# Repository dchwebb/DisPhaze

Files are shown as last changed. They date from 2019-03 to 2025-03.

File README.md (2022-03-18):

# Dis Phaze
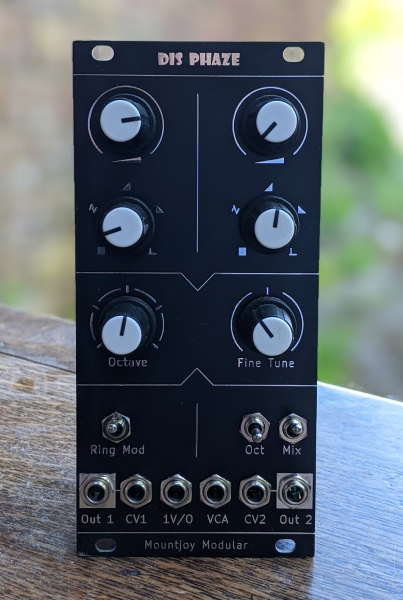
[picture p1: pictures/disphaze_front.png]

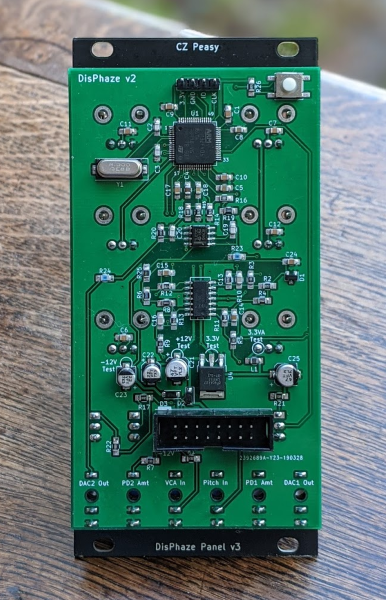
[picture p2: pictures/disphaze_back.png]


Eurorack module providing two Phase Distortion oscillators based on Casio's CZ synthesizors. 

Phase distortion involves warping a sine wave using a second phase distortion signal. The phase distortion tables in this module were loosely based on waveforms sampled from a Casio CZ-1000. Both oscillators allow the sine wave to be warped by a greater amount than on the original and in the case of oscillator 1 the phase distortion tables can be continuously varied.

Functionality
-------------

Disphaze is a two channel design where each channel controls 5 phase distortion waves. These are used to change the playback rate of the audio wave which is always a sine wave. All of the PD waves are based on the CZ but some are generated mathematically, some literally sampled and converted from an original CZ-1000.

The module is duophonic – channel one has a bit more range and so can go more extreme than the CZ. Channel one allows the PD waves morph from one to the next. The second channel does not morph and has a more limited range so it is a bit more 'authentic'. Channel two can also be offset by an octave from channel one which is particularly useful for ring modulation. The module works well in stereo with the two channels split left and right.

Channel one has a Ring Mod switch which digitally multiplies both channel ouputs. Channel two has a mix switch which adds both channel outputs.

The amount of phase distortion applied can be controlled with a knob and/or CV input. Pitch is applied with a 1V/Octave input which is also normalled to the Doepfer standard 16 pin Eurorack connector. The module is also supplied with a VCA input - this allows the use of an envelope generator (or other CV source) to control volume without the need for an external VCA.

Calibration
-----------

 * Set fine tune and both phase distortion amount knobs to the center position
 * Connect a voltage source to the 1V/Oct input
 * Press the calibration button once (top right of back of PCB) - a square wave will be output on channel 1
 * The top left knob will adjust the tuning offset (will be affected by spread setting)
 * The top right knob will adjust the tuning spread (test by checking different octaves)
 * When the calibration is complete press the calibration button again to save

Technical
---------

The heart of the module is the STM32F405 microcontroller running at 168MHz. Timing is generated with an external 8MHz crystal oscillator. CV inputs are conditioned with an MCP6004 OpAmp. The outputs are derived from the Microcontroller's 12 bit DACs amplified via a TL072 OpAmp. The microcontroller is programmed from a 4 pin SWD header.

The module uses a two PCB sandwich construction with vertical potentiometers and jack sockets connecting the two PCBs and providing structural rigidity.
 
 Errata
 ------
 
 * On v2 of the PCB the BOOT0 pin (pin 60) is floating which causes problems programming and debugging over the SWD interface. A bodge wire connects this to ground (pin 2 of C9).
 * Silkscreen for C4 and C17 are incorrectly swapped
 * VDDA is missing decoupling capacitors
 * Reset button missing
 * USB/UART not exposed
 * No silkscreen on calibrate button
 
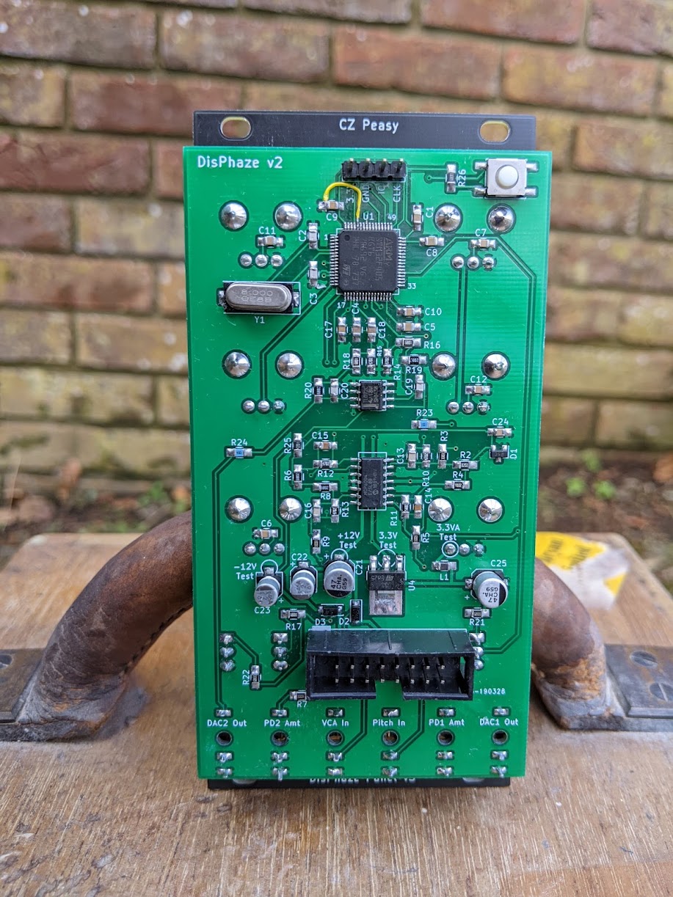
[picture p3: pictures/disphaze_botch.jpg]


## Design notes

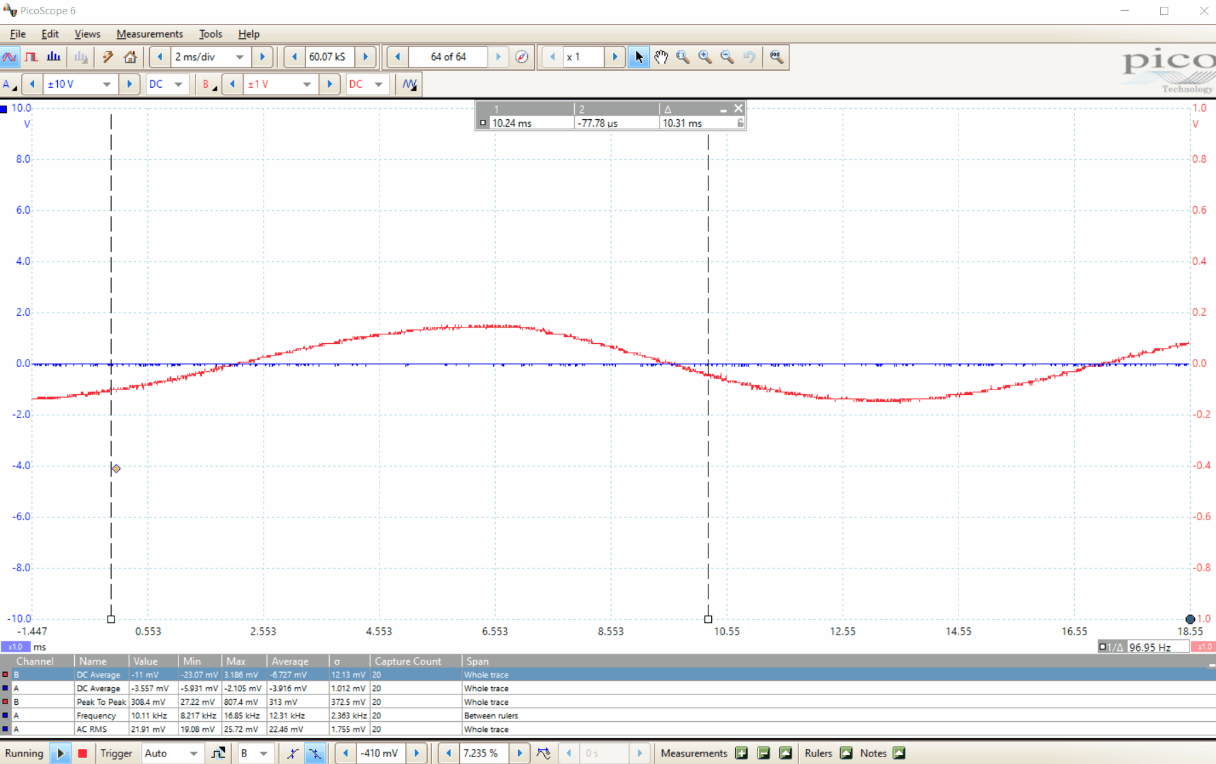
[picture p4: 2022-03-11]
pictures/Casio.gif

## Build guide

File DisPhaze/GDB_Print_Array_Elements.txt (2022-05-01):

In CubeIDE Debugger Console :

#Allow unlimited number of elements to be printed:
set print elements 0

# Prevent <repeats XXX times> messages in print out
set print repeats 0

# Print 10000 elements from array 'buffer' in hex format
print /x *buffer@5000

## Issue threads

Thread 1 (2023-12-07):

What is the Open Source License for this code?

eclab, 2023-12-07:
I'd like to use this code, but it lacks a license.  Can you tell me what license it is distributed under?

eclab, 2023-12-08:
I appreciate this, but without a license, it's a copyright violation use your code: you fully own the copyright.  What a license does is formally declare that we have the right to you use your code and under what conditions.

If you're in the category of "do whatever you want with this", I suggest Apache 2.0, which is a license just like this.  Just slap the Apache 2.0 license text in the top directory of the project, called LICENSE, and call it a day.  Don't even bother modifying the file headers, it's not that important.

dchwebb, 2023-12-08:
Added Apache licence.

eclab, 2023-12-08:
I'm working on a small project for adding PD to Mozzi on the Arduino.  I'm looking for simple PD versions for all the casio waves.  BTW, I think you've been replicating waves from the front panel of the CZ series, but you might be interested that the front panel lies: the way the waves work is entirely different.  In fact, there are eight waveforms, only one of which is "resonance" so to speak (it's often called "multi-sine"), and waves consist of pairs of waveforms plus a window function: there are eight window functions.  So there are technically 8^3 combinations, not 6, though many are duplicates and others are useless.  It'd be really nice to have distortion generators for all eight (well, 7) of the basic waveforms, the rest is easy to put together.  See [the Casio CZ-1 Splunking page](https://www.kasploosh.com/cz/11800-spelunking/4-window/), which is good at explaining it, though it doesn't give any clues as to the specific functions for doing distortion.  [This guy](https://www.kvraudio.com/forum/viewtopic.php?t=201858) got good generators for Saw and Square, and built a resonance function but that's not how resonance works in the CZ: it's just increasingly high-frequency Sine run through a triangle window function.  I've not found any other useful code.

eclab, 2023-12-08:
I am confused a bit by your PD code.  I think you have a fixed PD generator for (say) sawtooth in the form of a lookup table, and what you're doing is cross-fading between it and sine, rather than using parameterizable function generator?  I could be mistaken?  It's not super clear.  This might work in a pinch and I might do that but was hoping to actually find a fast (non-float, non-division, sine only via lookup table) way to produce the distortion functions.

dchwebb, 2023-12-08:
There are a couple of mechanisms going on here. The 'resonance' waves are implemented pretty much how the hardware works.

For the other waves my approach was to 'move' through a sine wave with the speed dictated by the phase distortion look-up table. I then sampled the phase distorted waves from my Casio CZ, built a little program to calculate the look-up table, and stored that.

So I'm not cross-fading between the phase distortion look-up and the sine wave; I'm dynamically adjusting the speed I play back the sine wave based on the scaled phase distortion wave. It's phase distortion, but implemented very differently to the Casio.

I wasn't really aiming for accuracy - more to make a fun homage to the Casio that would work in a Eurorack situation. The sounds tend to be more aggressive than the original and work well in a monophonic situation whereas the original Casio excels as a polyphonic synth (to me, anyway).

eclab, 2023-12-08:
I wonder if that would work in my situation. Lookup tables always good -- I'm on an arduino with no hardware division nor floating point -- but the whole architecture might be too computationally costly... [I'm doing AE Modular GRAINS].

dchwebb, 2023-12-08:
That makes it a lot harder - I am way too lazy to work with fixed point maths. I will generally try and avoid divides anyway, unless they can be implemented as integer bit shifts.

I haven't delved massively deeply into the Casio architecture (the patent document is available but is incredibly complicated). However I am fairly sure they would have used a much simpler method than me for performance on older processors.

I also think that one thing that has a fairly significant impact on the sound is the analog LP filter on the output. I don't know what they are using exactly - it is marked 'LPF17K' on the schematic, so I assume it is filtering at 17 KHz.

eclab, 2023-12-08:
I'm guessing this was an attempt to eliminate aliasing? Or high frequency DAC artifacts?    Probably not filtering prior to downsampling?

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

dchwebb, 2023-12-08:
I'm not exactly sure. The DAC goes to an 'Expander Circuit' and then a 'Sample/Hold Circuit', before being filtered and output. I haven't really looked into what these do but possibly create artifacts that need to be filtered.

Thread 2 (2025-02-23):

New V3 build help

OryH, 2025-02-23:
I ordered the V3 pcb and got it to run on the Disphaze.bin but the two switches on the right (octave and mix) and the led dont seem to work. I then tried uploading the newer DisphazePoly version and just get silence. Im new to the stm32cubeide so if there is anything I should know to get it working I would be greatful.  Thank you for the work you have done on this awesome module I look forward to using it in the years to come. Ory H.   ( I also built the entire module a second time and got the exact same issue)

dchwebb, 2025-02-23:
The v3 hardware should be used with the Poly firmware here: https://github.com/dchwebb/DisPhaze/tree/master/DisPhazePoly/Debug

If you hear nothing when it is connected try connecting an envelope to the VCA input.

The octave switch should be an On-Off-On type and the Mix switch should be an On-On type. Both switches just affect the output of the second channel 'Out 2', so will not have an effect on the 'Out 1' output.

The LED is a dual LED arranged as Anode-Cathode-Anode (some are the other way round).

Finally can you confirm that the crystal is 12MHz?

Let me know if any of that helps.

dchwebb, 2025-02-24:
Also a bit more explanation on the v3 hardware/poly firmware. This was designed as an experiment to create a polyphonic version of the module. You can switch between monophonic/polyphonic modes by long-pressing the button on the front. In monophonic mode connect a 1/v oct pitch signal and (optionally) an envelope to the VCA to control level.

In polyphonic mode you need to first set up an envelope for the notes. Attach an ADSR envelope to the ENV input and then press the button. You then trigger an envelope which will be sampled into the module. Once the envelope is sampled the module will play back the polyphonic notes using envelopes based on the ones sampled.

In polyphonic mode note input is via MIDI - either the USB connection or using a 3.5mm MIDI signal to the 1V/O input (note you need a stereo input jack for this to work.

I did have some problems with the action button on my original prototype. This is originally connected to pin PB5 but I bodged in a connection to PB10 which the firmware is currently configured for. I'll try and do some more testing to see if I can get it working with PB5 to avoid you having to carry out this fiddly bodge yourself.

OryH, 2025-02-26:
Thank you for the help. I built a third module with a new batch of stm32f405rgt6 from aliexpress and it didn't work at all so then i swapped it with a known working one from digikey and it worked but again only running the original disphaze.bin file. So maybe that could be a clue as I could have a different version of stm32 then the one you were running. I also replaced the 12mhz crystal and the 30pf caps and swapped all the 100nf decoupling capacitors around the microcontroller and still the same. Ill keep trying and If I figure it out ill post here. Either way it sounds really good even in its monophonic mode.

OryH, 2025-03-01:
Yes I will totally send it over to you if that helps you design these awesome modules. With the older firmware I can get audio output from both channels, the VCA and CV's respond to cv, the envelope works as does the pitch input. However when I use the poly version firmware there is no sound output with midi over usb connected to a Monome Norns or using a 3.5mm jack connected to a Westlicht Performers midi out etc..  It could be an issue with my midi gear some my soldering or some other problem. Let me know where to send the module and I greatly appreciate your help.

Ory H.

dchwebb, 2025-03-01:
If you send a message to dchwebb@gmail.com I'll give you my address.

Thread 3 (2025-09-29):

audio output level to low with my old version Hardware 3.0

tsanderakis, 2025-09-29:
Was working the last two weeks on a DisPhaze 3.0. The PCBs came some month ago.
Everything seems to work fine, all pots and switches, VCA LED going on/off when a gate is connectet but audio output level is to low when standing side by side to kishoof. Something wrong from my side or is there any chance to push the level a little bit more up?
And, because could not find a photo, had some trouble with the orientation of ÚSB port.  Could not not find the 1 and I`m not shure if it is the right way around. The firmware went by Disco Board onto the module.

dchwebb, 2025-09-29:
Just to confirm - is this the 3.0 rather than the 3.5 version? In any case the gain of the output is set by the resistors R17/R18 and R21/R22. So if you built the v3.0 version you have 68k/6.8k = 10x gain.

The output level could also be affected by R19 and R23. These are output protection resistors and are probably too high. You could try changing them for 100 ohm resistors and seeing if that helps.

I don't have the module in front of me but will find it and check orientation of USB.

tsanderakis, 2025-09-29:
ok, thank you. Will check this later.
In the moment I have a new module from Maffez from Austria on the table and try to get it ready to give him some response.
Could not get it ready last week because out of 3,5 mm jacks. But they are in the mail for today.
It`s the older 3.0 version. In the moment USB is not connecting to computer. Ok, could also be some cold joints.

tsanderakis, 2025-09-29:
Then I hope that I don`t have tu turn around the USB socket. In the moment the connection is not working and a few days ago I turned it around because it was also not working. But what is now the right direktin? When looking to the front the small part is pointing down to bottom. Could not find the 1 marking on the socket. PCB is fine.

dchwebb, 2025-09-29:
I can't find the module at present (we have just moved house) but it should look like this (I think):

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

tsanderakis, 2025-09-29:
Then I`m the wrong way around. Then it needs a little bit surgery on the kitchentable and I hope that I will not destroy something.
Good that I have not soldered the ground, just the small 4 connectors.
Thank you for looking. Let you know late if everything went good.

tsanderakis, 2025-09-29:
help
Mountjoy DisPhaze Poly - supported commands:

help           -  Shows this information
info           -  Display current settings
dfu            -  USB firmware upgrade
poly           -  Switches between polyphonic and monophonic mode
attack:x.xx    -  Set polyphonic attack time in ms
decay:x.xx     -  Set decay time in ms
sustain:x.xx   -  Set sustain 0.0 - 1.0
release:x.xx   -  Set envelope release time in ms
comphold:x.xx  -  Set compressor hold time in ms
comprel:x.xx   -  Set compressor release rate
compthresh:x.xx-  Set compressor threshold
info
Build Date: Mar 23 2025 12:01:45
Polyphonic mode: off
VCA Envelope: A: 1.00 ms, D: 50.00 ms, S: 0.50, R: 50.00 ms
Compressor: Hold time 350.00 ms; Release: 0.00000010; Threshold: 0.50
Calibration base: 2220.42, mult: 587.00
Config sector: 8; address: 0x8080000

looks good but where are my octaves?

dchwebb, 2025-09-29:
Fair point. You have to type 'calib'.

tsanderakis, 2025-09-29:
Some strange things were going on. Kicked the Seabooard out of the chain and replaced it with my old Midiplus 61.
When calibrating I used my Ornament & Crime and this was calibrated with a multimeter with 60.000 reading, so for me ok.
When changing the octaves from O&C, 0V, 1V, 2V, 3V.... everything was fine.  Going to MidiMonger octaves were not ok with Seaboard and PSU.
Replaced then Seaboard by Midiplus 61 to have something simple and now the STM on DisPhaze was running hot switching my test PSU on and off like hell and the STM is hot that you can burn your finger.
For the moment I try to cool it down and check later after some food and a beer if it is still alive. If not, things are goin complicated.
First I was thinking to cool the STM down with spray but I have the time to do it in natural way.

tsanderakis, 2025-10-04:
Could not find out whats wrong with No. 1. Checked all connections with big magnifying glasses  and lots of light.
Last chance is maybe changing the STM.
Started with a second one, No.2.
Don`t wanted to have a surprise and checked it before mounting potentiometers and other stuff. Same problem?
Later I will do No3. from the same batch of processors and just soldering the processor and nothing else. If I have the same problem then there must bei somemething wrong with PCBs or are the processors fake??

dchwebb, 2025-10-05:
Apologies I am away in Japan so can't access my computer. However I think
there was a problem with one of the buttons on the module shorting to
ground. I did a fairly fiddly hardware botch to resolve and then released
v3.5 to fix. Unfortunately it looks like your pcbs are the old version.
When I am back I will have a more detailed look at the hardware botch I
made. In the meantime I don't recommend trying to build any more as I don't
think it will help.
Sorry not to be more helpful at this stage!

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

tsanderakis, 2025-10-05:
Thank you.
Have a nice trip.

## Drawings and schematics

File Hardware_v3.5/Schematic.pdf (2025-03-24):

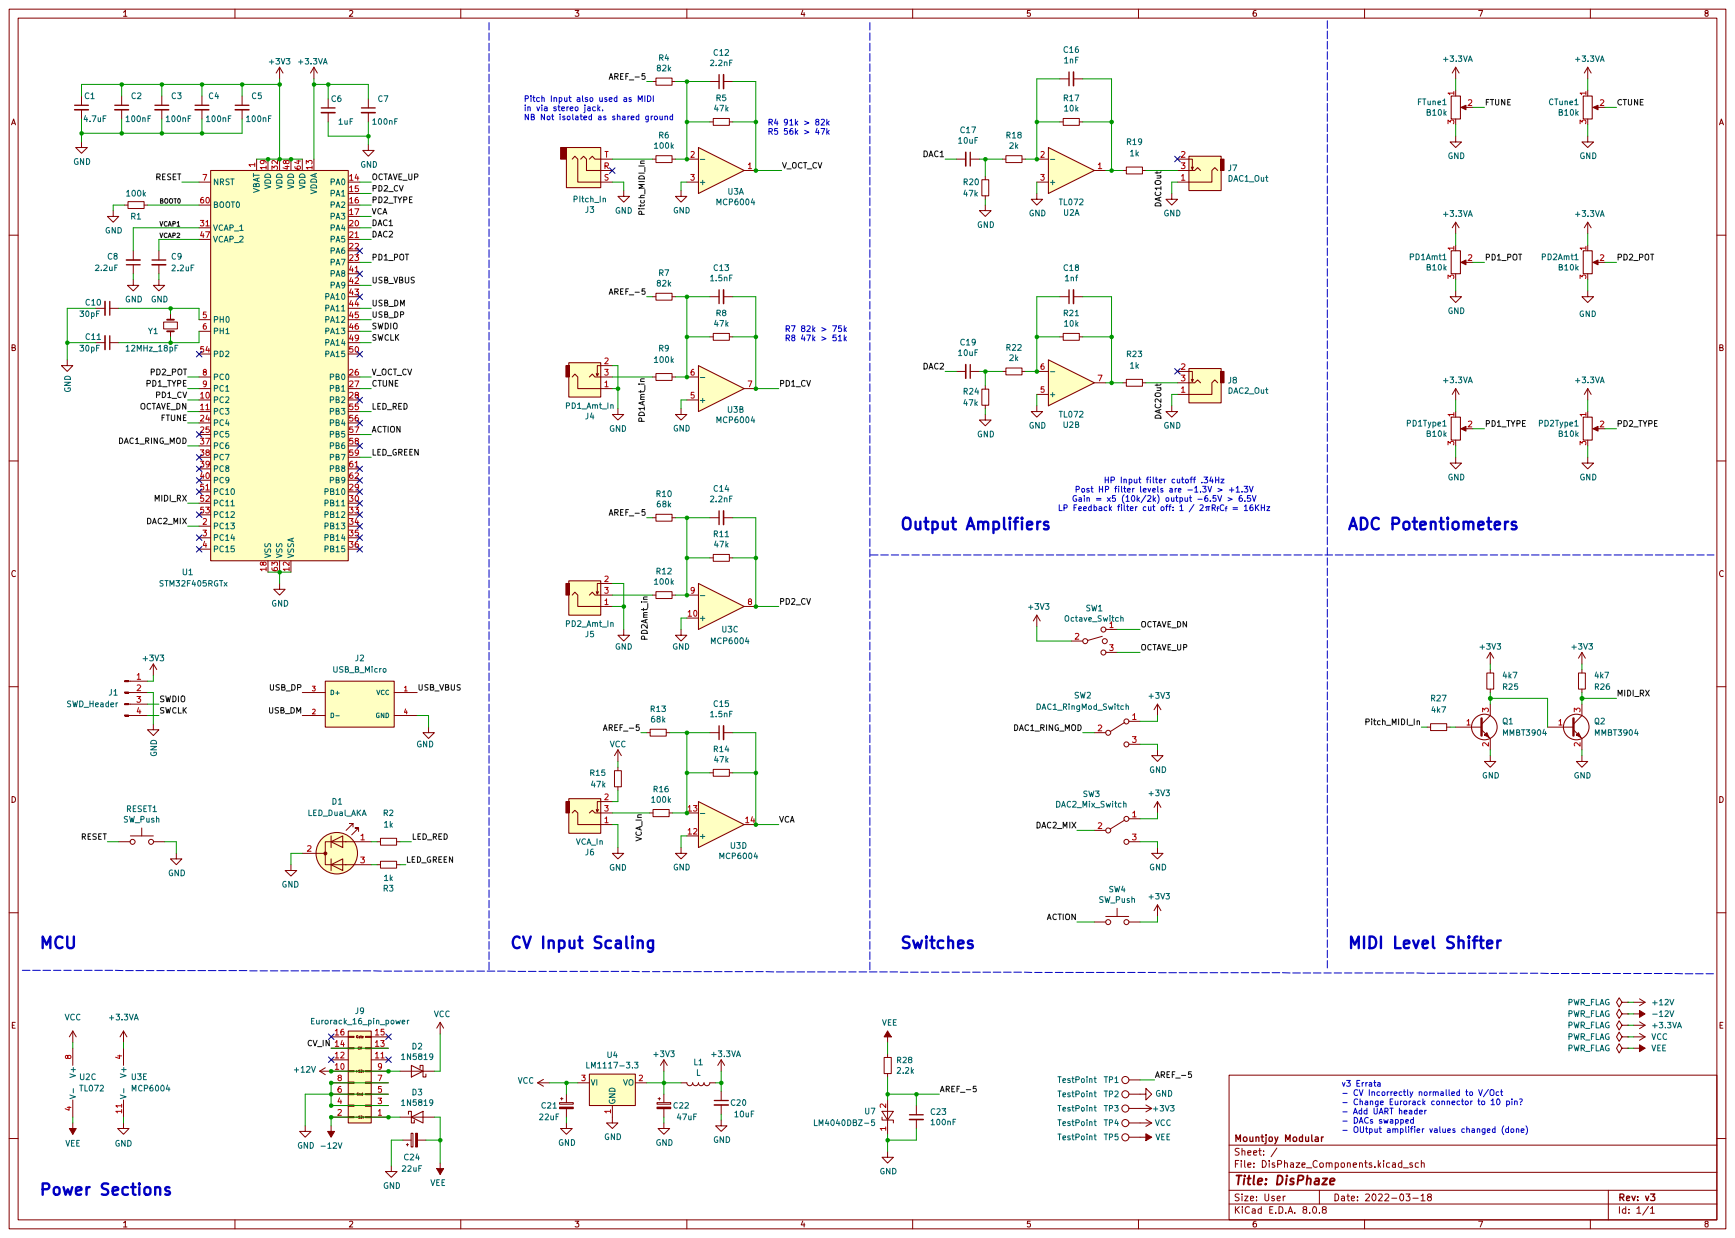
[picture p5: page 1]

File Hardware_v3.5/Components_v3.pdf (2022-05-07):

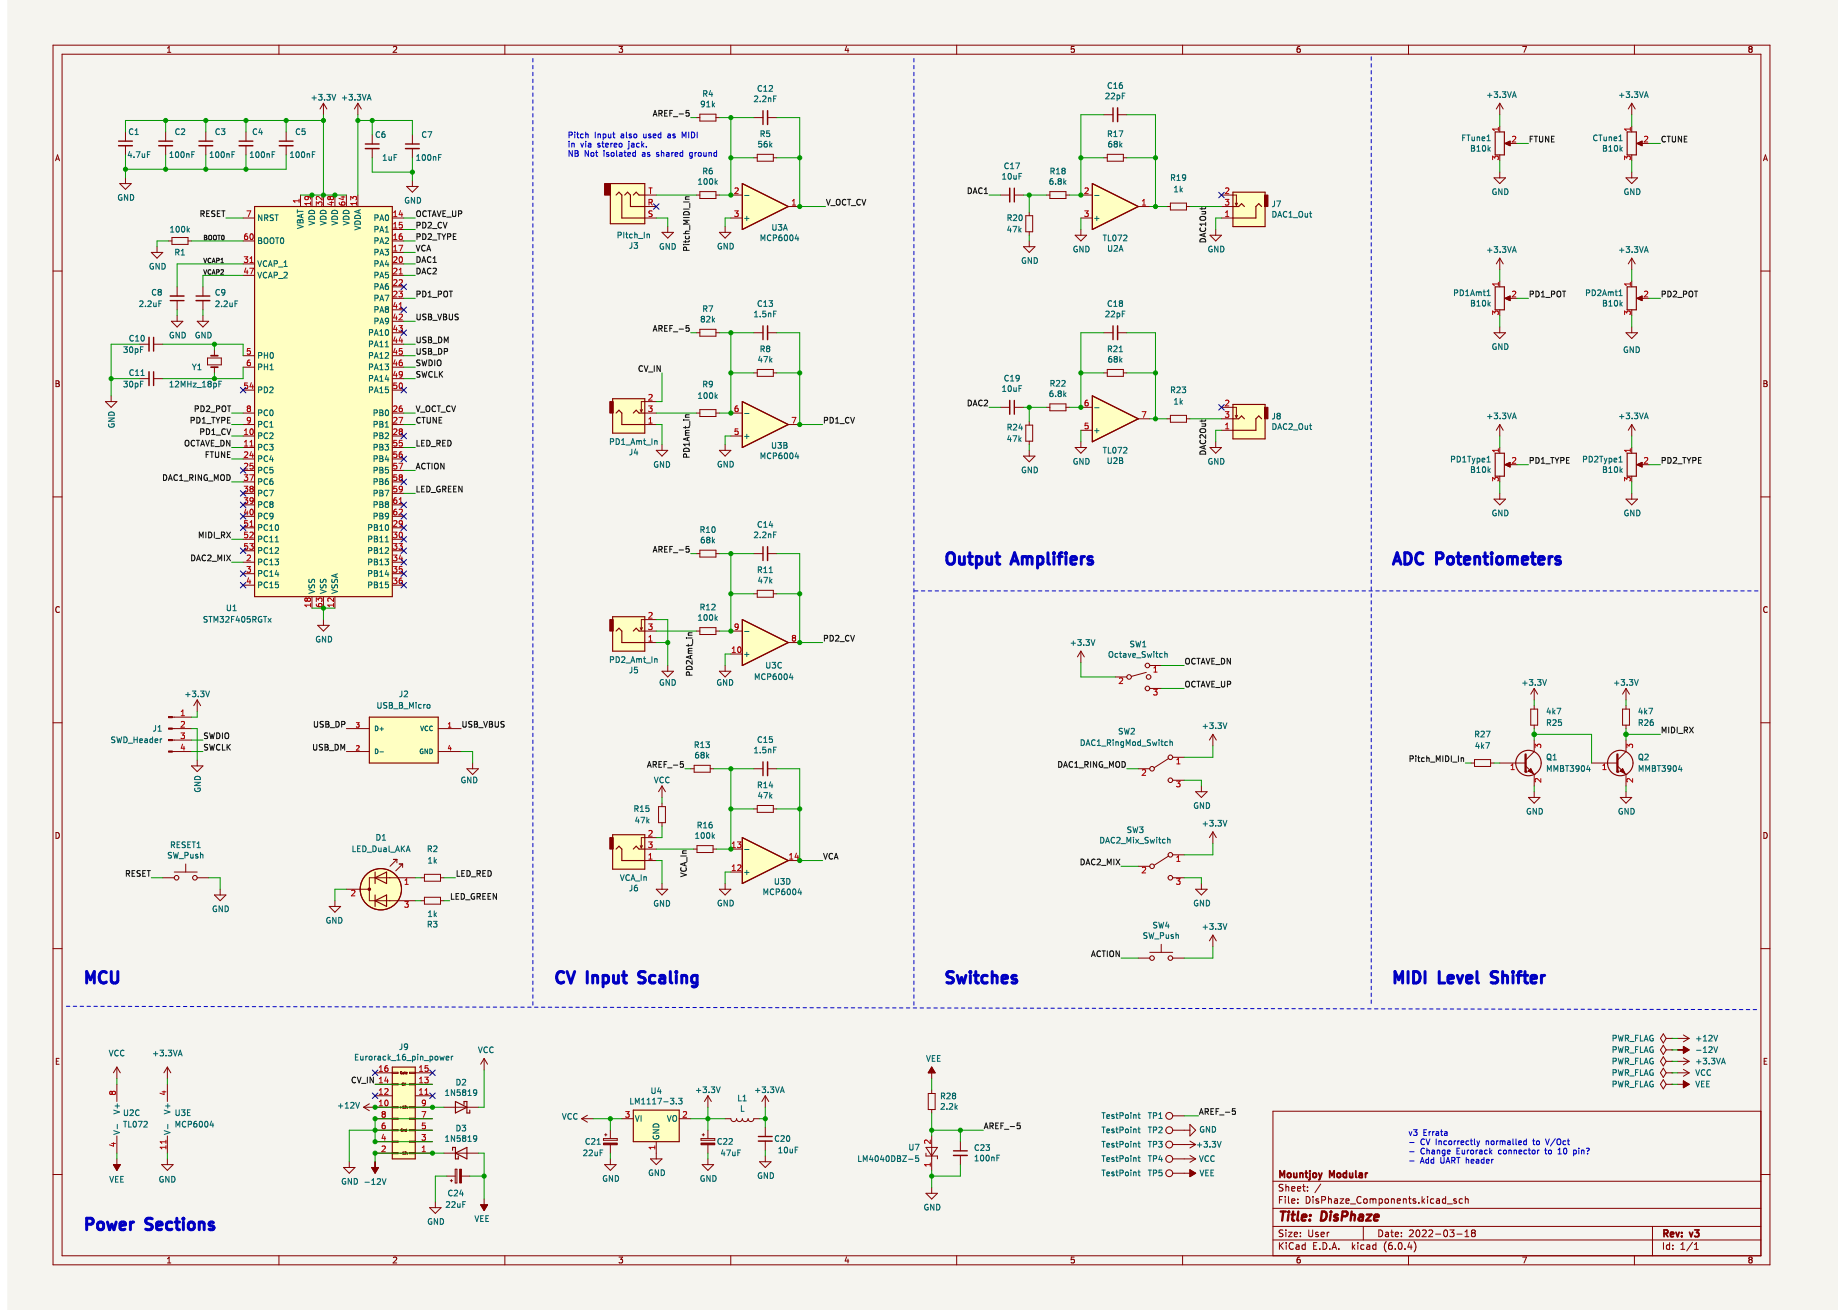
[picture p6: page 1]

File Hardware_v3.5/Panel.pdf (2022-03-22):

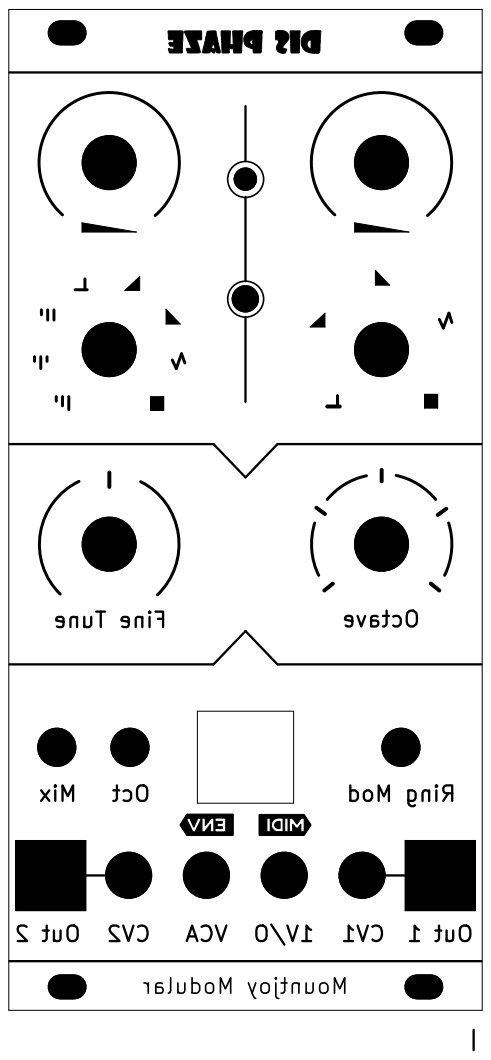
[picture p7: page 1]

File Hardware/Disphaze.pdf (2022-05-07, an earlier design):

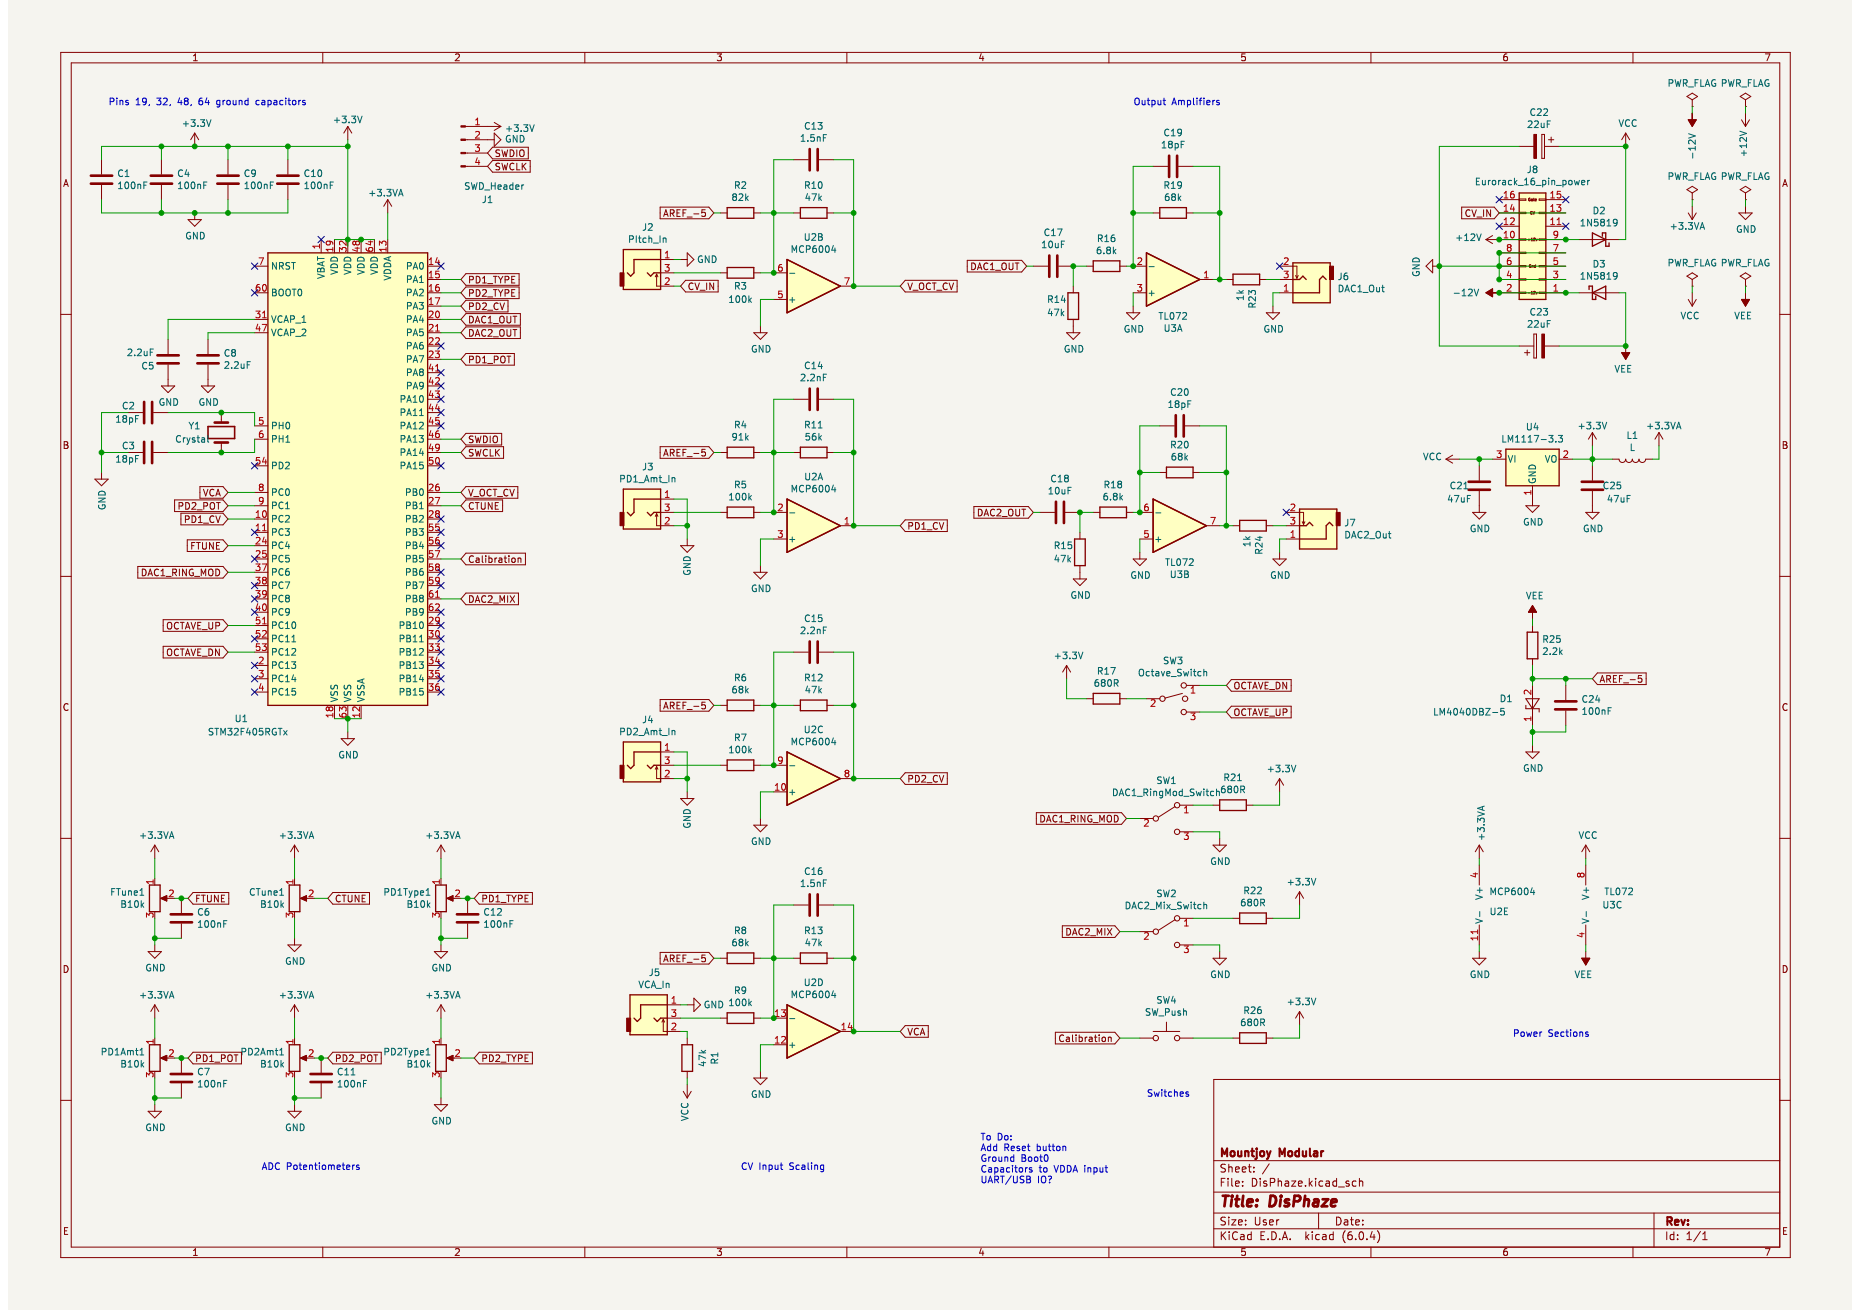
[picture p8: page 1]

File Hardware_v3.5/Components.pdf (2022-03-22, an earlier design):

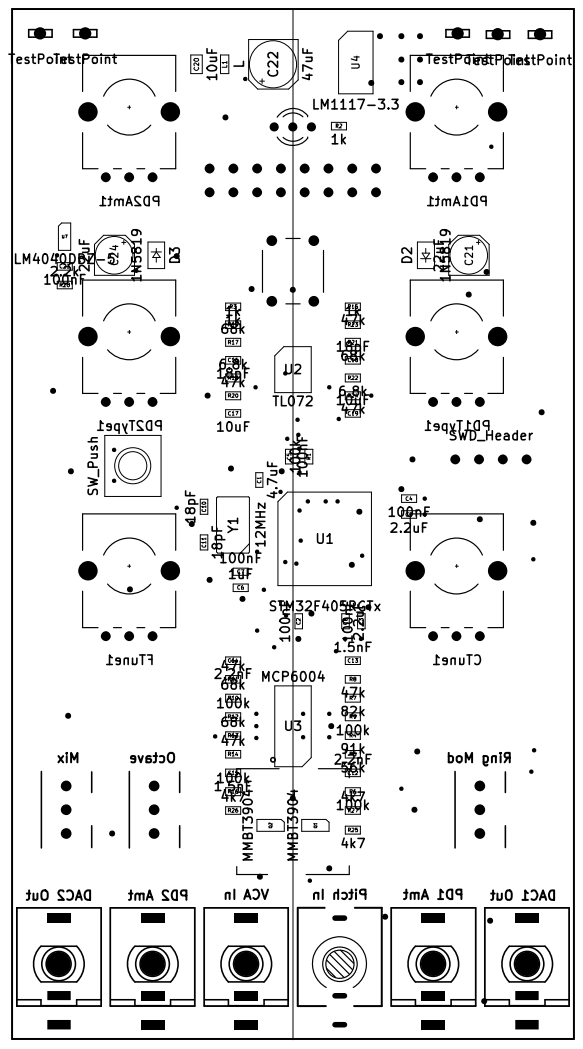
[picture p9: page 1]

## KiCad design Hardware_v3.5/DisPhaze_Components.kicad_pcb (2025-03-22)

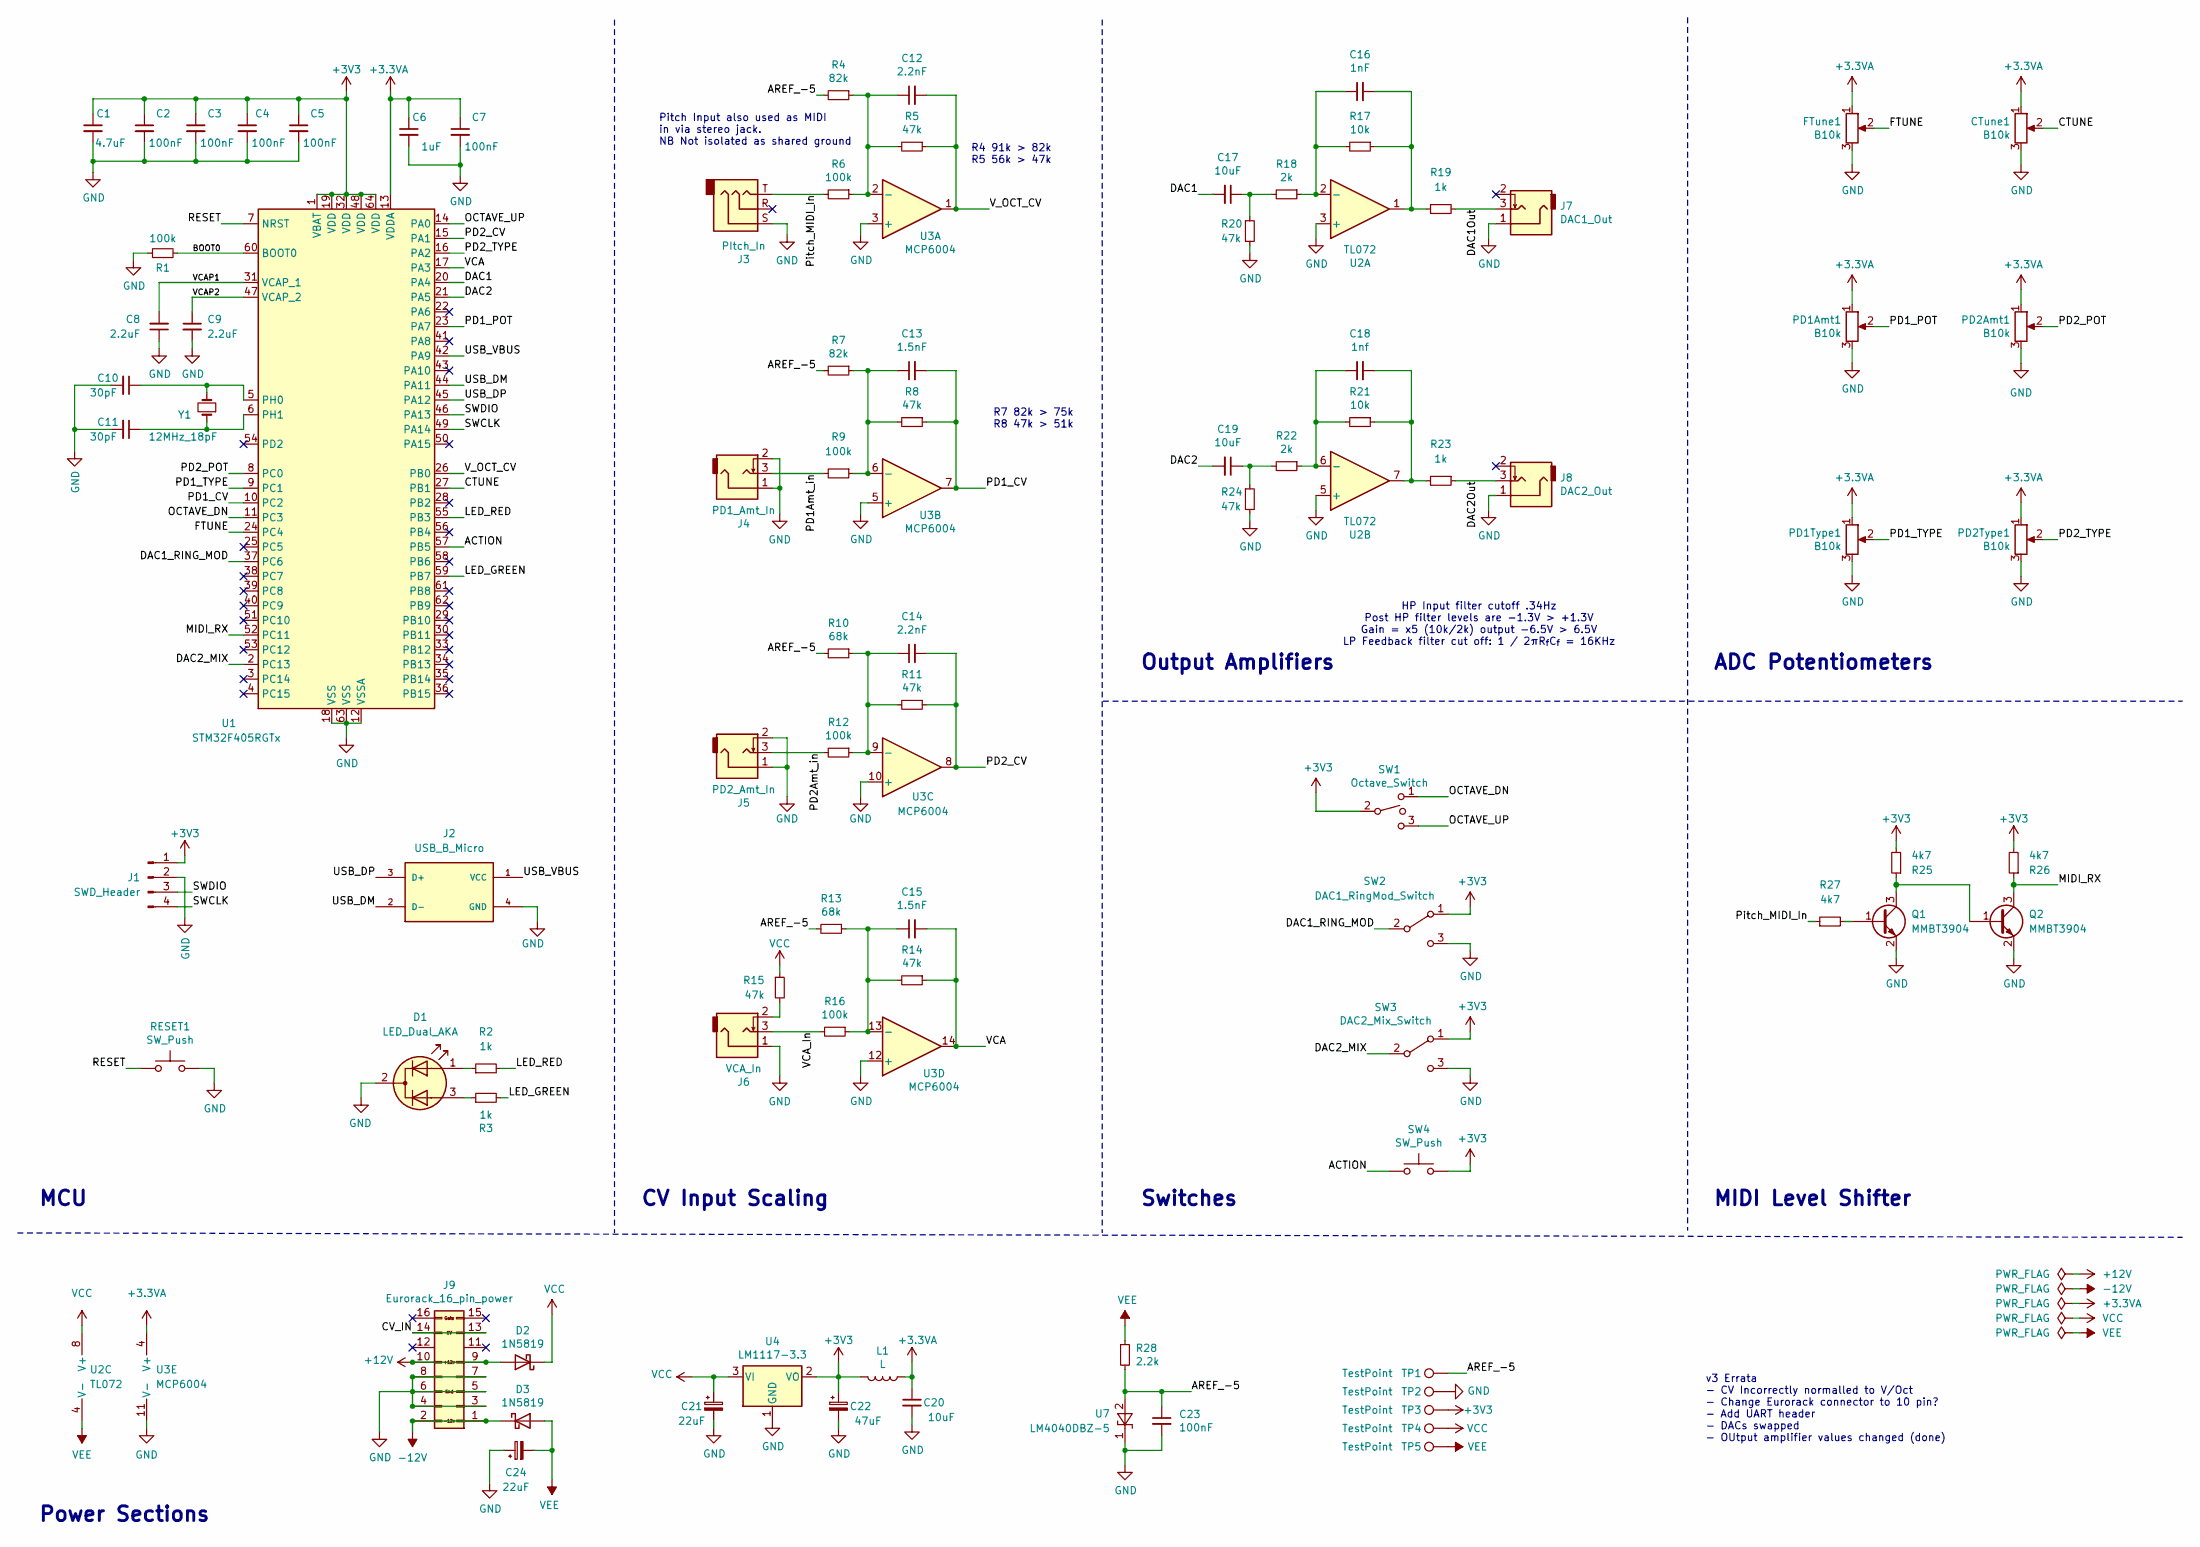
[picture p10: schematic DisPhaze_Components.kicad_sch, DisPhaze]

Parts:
C1: 4.7uF; C_0603_1608Metric
C2, C3, C4, C5, C7, C23: 100nF; C_0603_1608Metric
C6: 1uF; C_0603_1608Metric
C8, C9: 2.2uF; C_0603_1608Metric
C10, C11: 30pF; C_0603_1608Metric
C12, C14: 2.2nF; C_0603_1608Metric
C13, C15: 1.5nF; C_0603_1608Metric
C16: 1nF; C_0603_1608Metric
C17, C19: 10uF; C_0603_1608Metric
C18: 1nf; C_0603_1608Metric
C20: 10uF; C_0805_2012Metric
C21, C24: 22uF; CP_Elec_4x5.3
C22: 47uF; CP_Elec_5x5.4
CTune1: B10k; Alpha_9mm_Potentiometer_Aligned
D1: LED_Dual_AKA; LED_D3.0mm-3
D2, D3: 1N5819; D_SOD-123
FTune1: B10k; Alpha_9mm_Potentiometer_Aligned
J1: SWD_Header; SWD_header
J2: USB_B_Micro; USB_TE_1734517-1
J3: PItch_In; Thonkiconn_Stereo-PJ366ST
J4: PD1_Amt_In; THONKICONN_hole
J5: PD2_Amt_In; THONKICONN_hole
J6: VCA_In; THONKICONN_hole
J7: DAC1_Out; THONKICONN_hole
J8: DAC2_Out; THONKICONN_hole
J9: Eurorack_16_pin_power; Eurorack_16_pin_header
L1: L; L_0805_2012Metric
PD1Amt1, PD1Type1, PD2Amt1, PD2Type1: B10k; Alpha_9mm_Potentiometer_Aligned
Q1, Q2: MMBT3904; SOT-23; Part_Number C20526
R1: 100k; R_0603_1608Metric; Part_Number C25803
R2, R3, R19, R23: 1k; R_0603_1608Metric
R4, R7: 82k; R_0603_1608Metric
R5, R8, R11, R14, R15, R20, R24: 47k; R_0603_1608Metric
R6, R9, R12, R16: 100k; R_0603_1608Metric
R10, R13: 68k; R_0603_1608Metric
R17, R21: 10k; R_0603_1608Metric
R18, R22: 2k; R_0603_1608Metric
R25, R26, R27: 4k7; R_0603_1608Metric; Part_Number C23162
R28: 2.2k; R_0603_1608Metric
RESET1: SW_Push; SW_SPST_EVQQ2
SW1: Octave_Switch; SPDTSubMiniature
SW2: DAC1_RingMod_Switch; SPDTSubMiniature
SW3: DAC2_Mix_Switch; SPDTSubMiniature
SW4: SW_Push; SW_PUSH_6mm_aligned
TP1, TP2, TP3, TP4, TP5: TestPoint; 1.3mm_Test_Point
U1: STM32F405RGTx; LQFP-64_10x10mm_P0.5mm
U2: TL072; SOIC-8_3.9x4.9mm_P1.27mm
U3: MCP6004; SOIC-14_3.9x8.7mm_P1.27mm
U4: LM1117-3.3; SOT-223-3_TabPin2
U7: LM4040DBZ-5; SOT-23
Y1: 12MHz_18pF; Crystal_SMD_0603-2Pin_6.0x3.5mm

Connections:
+3.3VA: C6.1, C7.1, C20.1, CTune1.1, FTune1.1, L1.1, PD1Amt1.1, PD1Type1.1, PD2Amt1.1, PD2Type1.1, U1.13 (VDDA), U3.4 (V+)
+3V3: C1.1, C2.1, C3.1, C4.1, C5.1, C22.1, J1.1, L1.2, R25.2, R26.2, SW1.2, SW2.1 (A), SW3.1 (A), SW4.2, TP3.1, U1.1 (VBAT), U1.19 (VDD), U1.32 (VDD), U1.48 (VDD), U1.64 (VDD), U4.2 (VO)
+12V: D2.2 (A), J9.9, J9.10
-12V: D3.1 (K), J9.1, J9.2
/ACTION: SW4.1, U1.57 (PB5)
/AREF_-5: C23.1, R4.2, R7.2, R10.2, R13.2, R28.2, TP1.1, U7.2 (A)
/BOOT0: R1.2, U1.60 (BOOT0)
/CTUNE: CTune1.2, U1.27 (PB1)
/CV_IN: J9.13, J9.14
/DAC1: C17.2, U1.20 (PA4)
/DAC1Out: J7.3, R19.2
/DAC1_RING_MOD: SW2.2 (B), U1.37 (PC6)
/DAC2: C19.2, U1.21 (PA5)
/DAC2Out: J8.3, R23.1
/DAC2_MIX: SW3.2 (B), U1.2 (PC13)
/FTUNE: FTune1.2, U1.24 (PC4)
/LED_GREEN: R3.2, U1.59 (PB7)
/LED_RED: R2.2, U1.55 (PB3)
/MIDI_RX: Q2.3 (C), R26.1, U1.52 (PC11)
/OCTAVE_DN: SW1.1, U1.11 (PC3)
/OCTAVE_UP: SW1.3, U1.14 (PA0)
/PD1Amt_in: J4.3, R9.2
/PD1_CV: C13.2, R8.1, U1.10 (PC2), U3.7
/PD1_POT: PD1Amt1.2, U1.23 (PA7)
/PD1_TYPE: PD1Type1.2, U1.9 (PC1)
/PD2Amt_in: J5.3, R12.2
/PD2_CV: C14.2, R11.1, U1.15 (PA1), U3.8
/PD2_POT: PD2Amt1.2, U1.8 (PC0)
/PD2_TYPE: PD2Type1.2, U1.16 (PA2)
/Pitch_MIDI_In: J3.T, R6.2, R27.1
/RESET: RESET1.1, U1.7 (NRST)
/SWCLK: J1.4, U1.49 (PA14)
/SWDIO: J1.3, U1.46 (PA13)
/USB_DM: J2.2 (D-), U1.44 (PA11)
/USB_DP: J2.3 (D+), U1.45 (PA12)
/USB_VBUS: J2.1 (VCC), U1.42 (PA9)
/VCA: C15.2, R14.1, U1.17 (PA3), U3.14
/VCAP1: C8.2, U1.31 (VCAP_1)
/VCAP2: C9.1, U1.47 (VCAP_2)
/VCA_In: J6.3, R16.2
/V_OCT_CV: C12.2, R5.1, U1.26 (PB0), U3.1
GND: C1.2, C2.2, C3.2, C4.2, C5.2, C6.2, C7.2, C8.1, C9.2, C10.2, C11.2, C20.2, C21.2, C22.2, C23.2, C24.1, CTune1.3, D1.2 (K), FTune1.3, J1.2, J2.4 (GND), J3.S, J4.1, J4.2, J5.1, J5.2, J6.1, J7.1, J8.1, J9.3, J9.4, J9.5, J9.6, J9.7, J9.8, PD1Amt1.3, PD1Type1.3, PD2Amt1.3, PD2Type1.3, Q1.2 (E), Q2.2 (E), R1.1, R20.2, R24.2, RESET1.2, SW2.3 (C), SW3.3 (C), TP2.1, U1.12 (VSSA), U1.18 (VSS), U1.63 (VSS), U2.3 (+), U2.5 (+), U3.3 (+), U3.5 (+), U3.10 (+), U3.11 (V-), U3.12 (+), U4.1 (GND), U7.1 (K)
unnamed: C16.2, R17.1, R19.1, U2.1
unnamed: C17.1, R18.2, R20.1
unnamed: C18.2, R21.1, R23.2, U2.7
unnamed: C19.1, R22.2, R24.1
unnamed: D1.1 (A1), R2.1
unnamed: D1.3 (A2), R3.1
unnamed: J6.2, R15.2
unnamed: Q1.1 (B), R27.2
unnamed: Q1.3 (C), Q2.1 (B), R25.1
unnamed: C10.1, U1.5 (PH0), Y1.2
unnamed: C11.1, U1.6 (PH1), Y1.1
unnamed: C16.1, R17.2, R18.1, U2.2 (-)
unnamed: C18.1, R21.2, R22.1, U2.6 (-)
unnamed: C12.1, R4.1, R5.2, R6.1, U3.2 (-)
unnamed: C13.1, R7.1, R8.2, R9.1, U3.6 (-)
unnamed: C14.1, R10.1, R11.2, R12.1, U3.9 (-)
unnamed: C15.1, R13.1, R14.2, R16.1, U3.13 (-)
VCC: C21.1, D2.1 (K), R15.1, TP4.1, U2.8 (V+), U4.3 (VI)
VEE: C24.2, D3.2 (A), R28.1, TP5.1, U2.4 (V-)

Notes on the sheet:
CV Input Scaling
v3 Errata - CV Incorrectly normalled to V/Oct - Change Eurorack connector to 10 pin? - Add UART header - DACs swapped - OUtput amplifier values changed (done)
Output Amplifiers
ADC Potentiometers
Pitch Input also used as MIDI in via stereo jack. NB Not isolated as shared ground
MCU
R7 82k > 75k R8 47k > 51k
Power Sections
Switches
R4 91k > 82k R5 56k > 47k
HP Input filter cutoff .34Hz Post HP filter levels are -1.3V > +1.3V Gain = x5 (10k/2k) output -6.5V > 6.5V LP Feedback filter cut off: 1 / 2πR_{f}C_{f} = 16KHz
MIDI Level Shifter

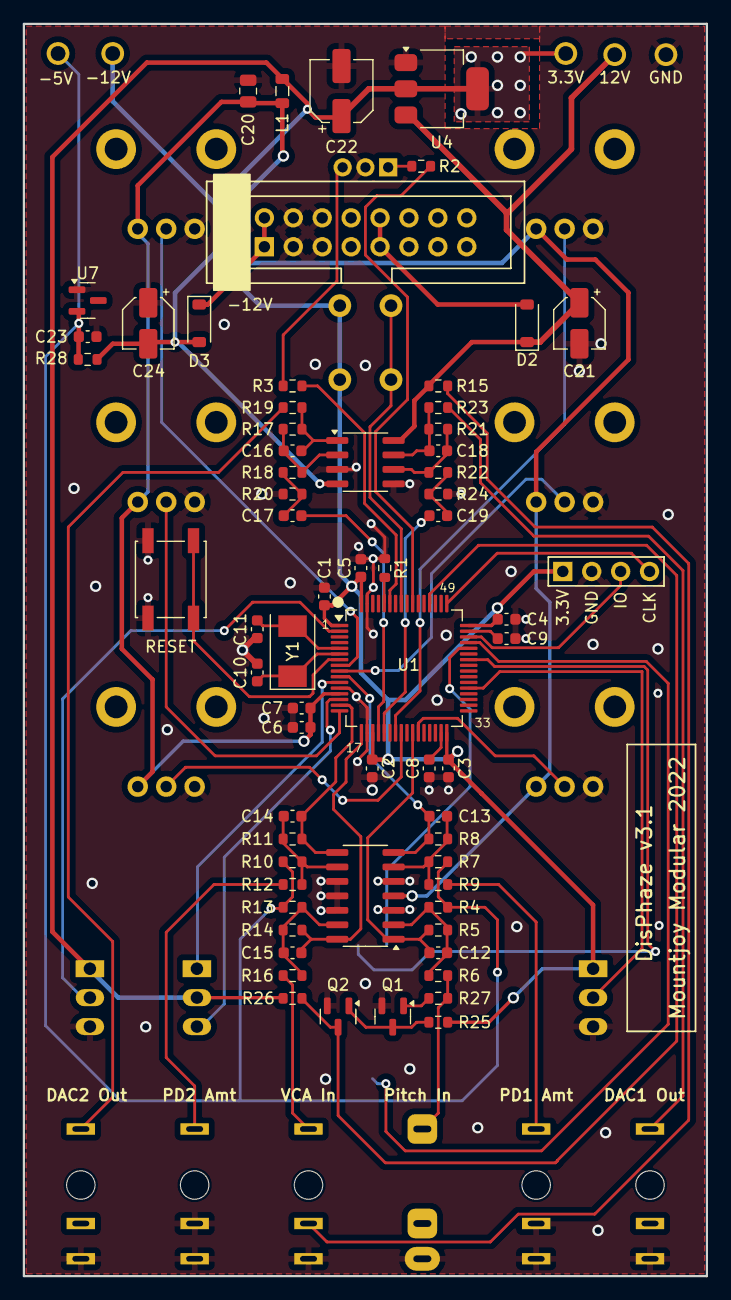
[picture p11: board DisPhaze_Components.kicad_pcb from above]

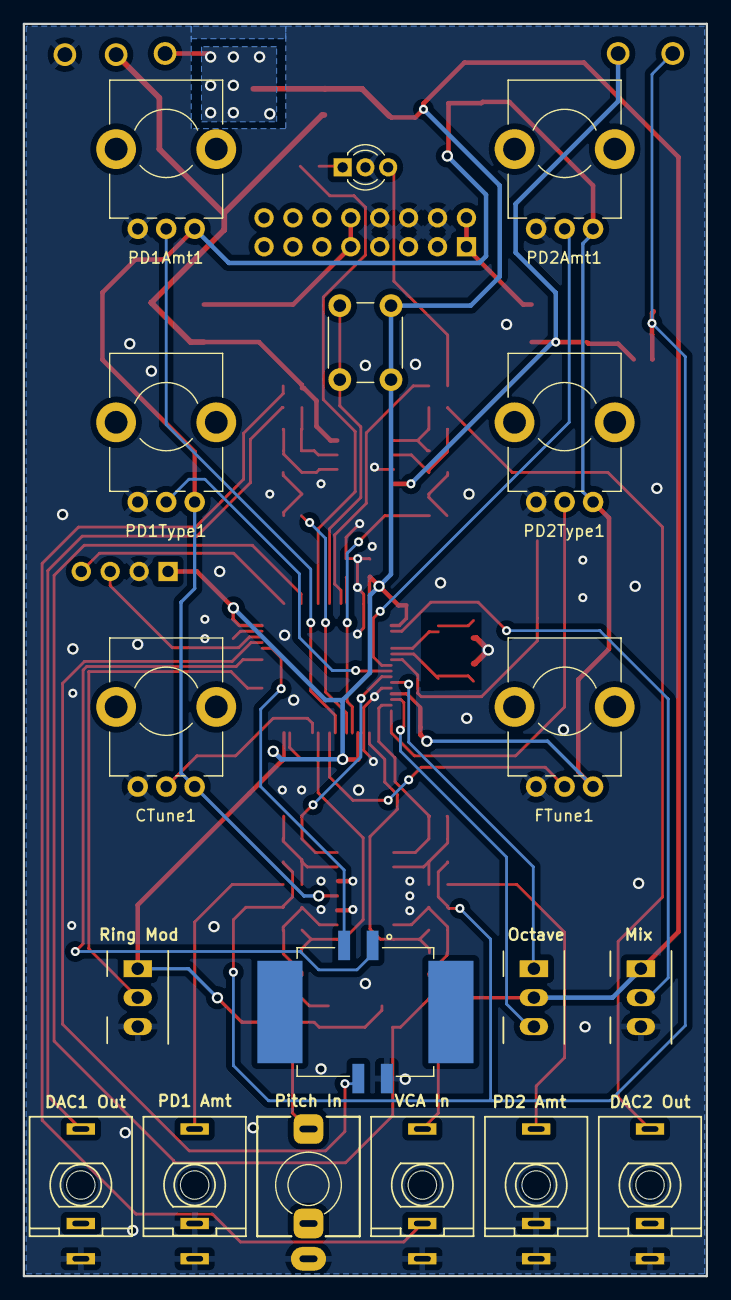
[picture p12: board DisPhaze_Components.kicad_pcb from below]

Board: 2 copper layers, 60.0 x 110.0 mm, 89 parts (18 on the bottom side), 61 nets.

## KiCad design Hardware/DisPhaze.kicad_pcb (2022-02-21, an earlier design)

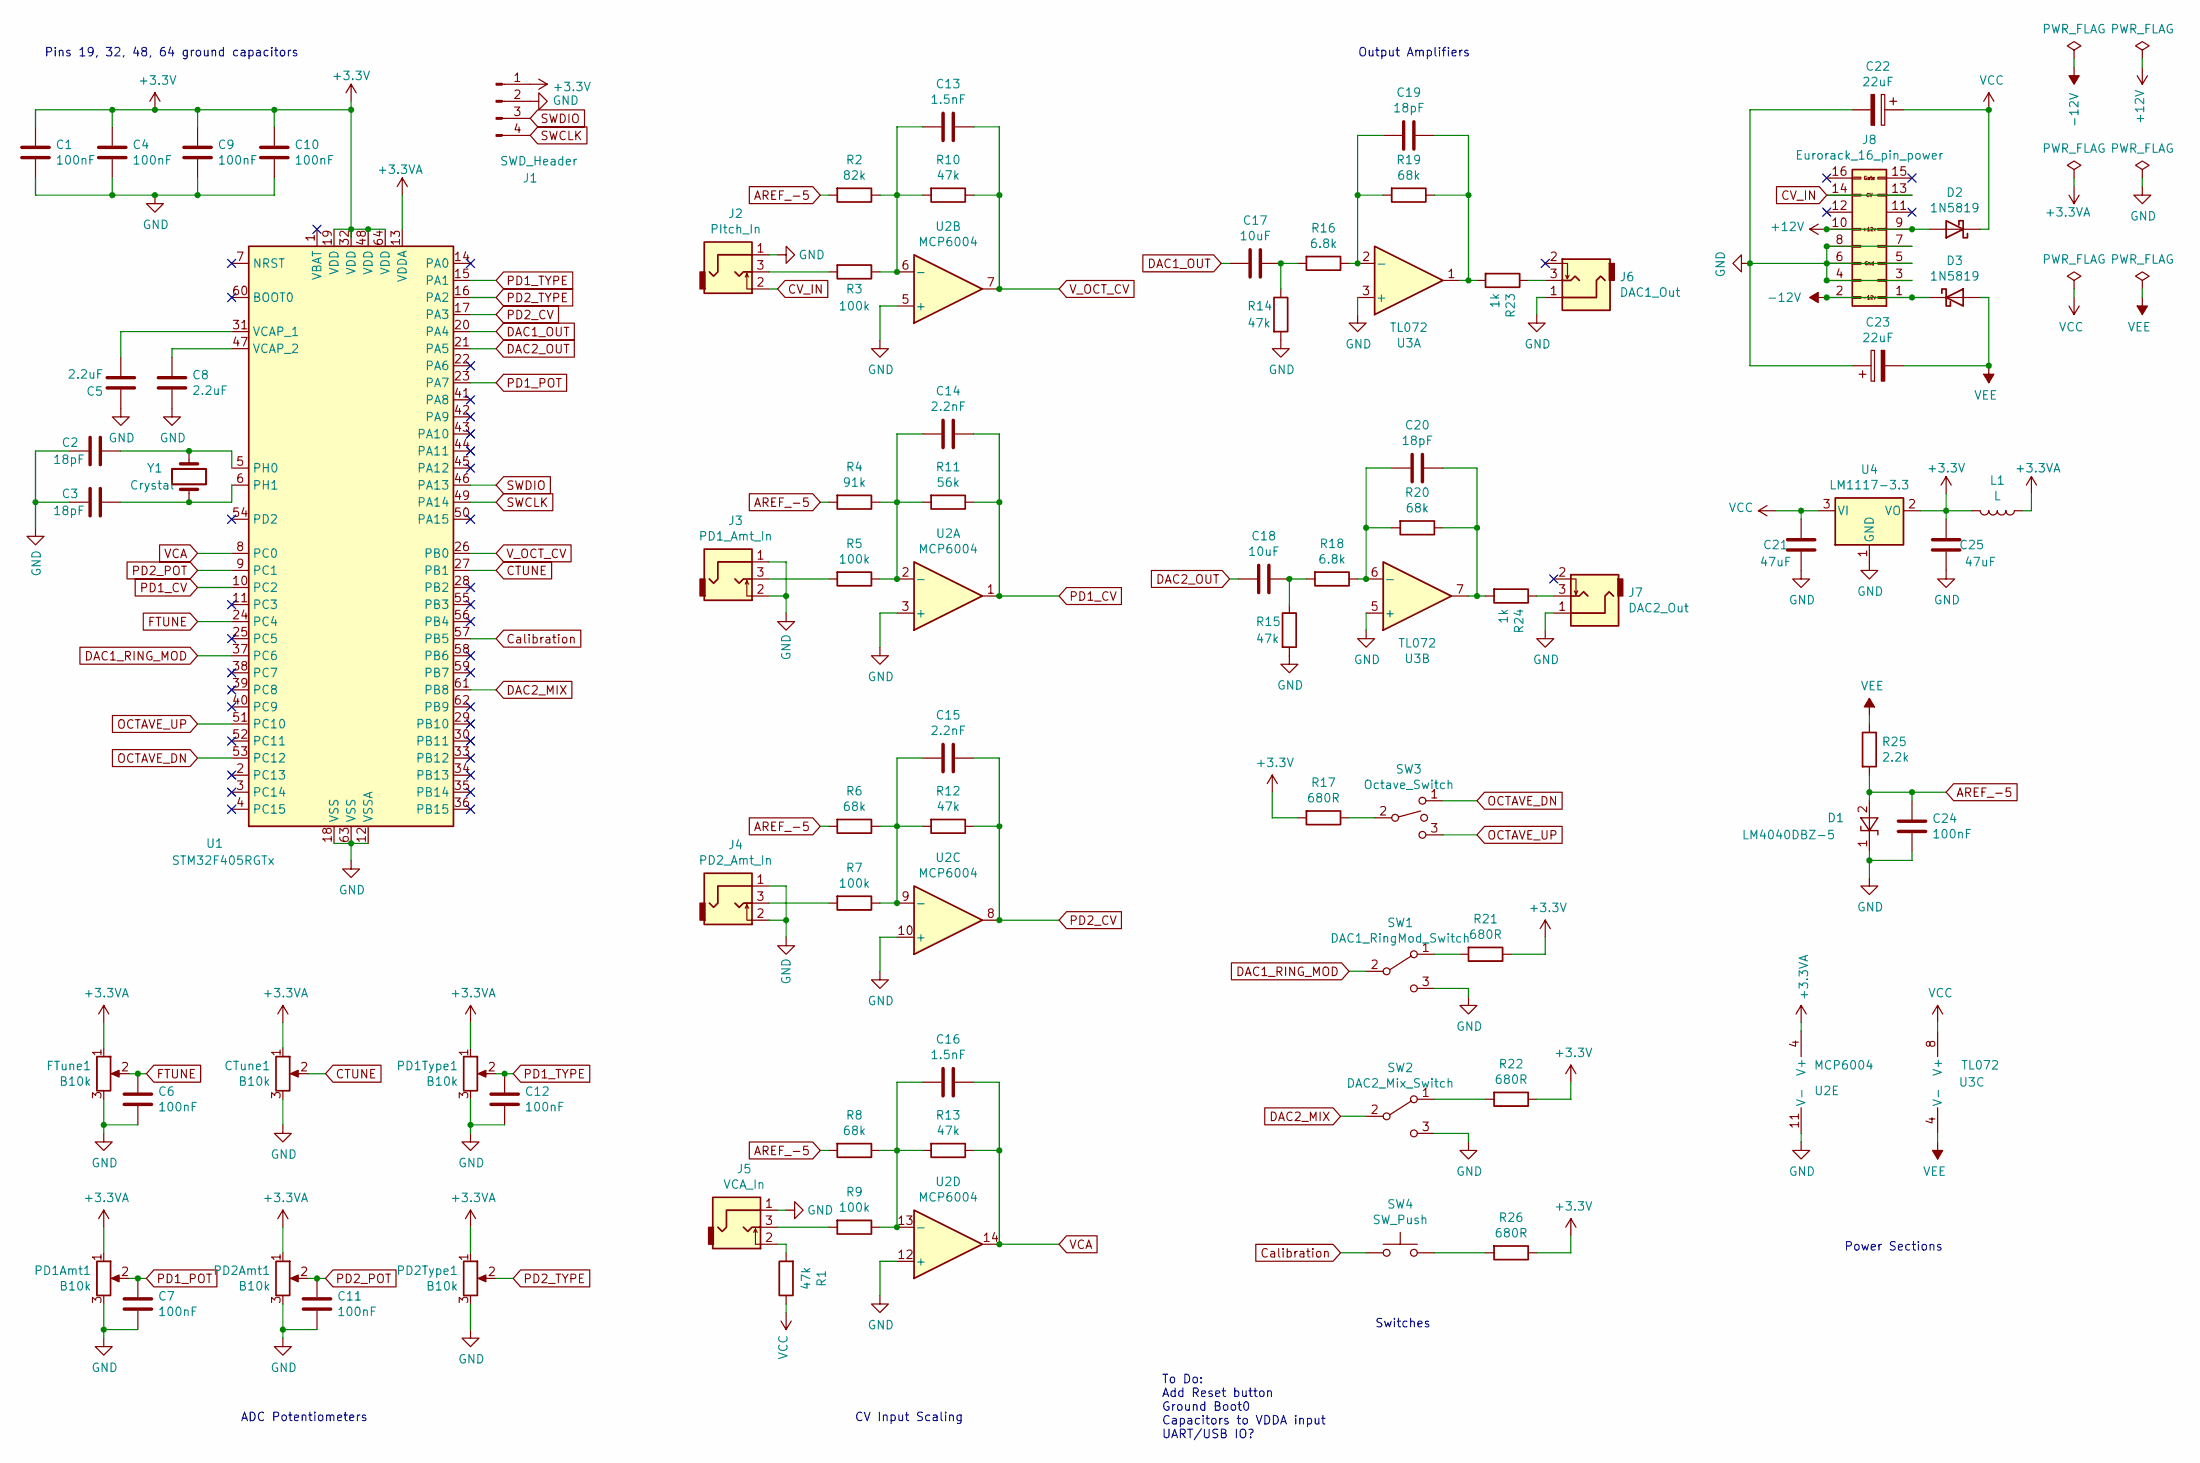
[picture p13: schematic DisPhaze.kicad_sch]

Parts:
C1, C4, C6, C7, C9, C10, C11, C12, C24: 100nF; C_0805_HandSoldering
C2, C3, C19, C20: 18pF; C_0805_HandSoldering
C5, C8: 2.2uF; C_0805_HandSoldering
C13, C16: 1.5nF; C_0805_HandSoldering
C14, C15: 2.2nF; C_0805_HandSoldering
C17, C18: 10uF; C_0805_HandSoldering
C21, C25: 47uF; CP_Elec_5x5.8
C22, C23: 22uF; CP_Elec_4x5.8
CTune1: B10k; Alpha_9mm_Potentiometer
D1: LM4040DBZ-5; SOT-23
D2, D3: 1N5819; D_SOD-123
FTune1: B10k; Alpha_9mm_Potentiometer
J1: SWD_Header; SWD_header
J2: PItch_In; THONKICONN_hole
J3: PD1_Amt_In; THONKICONN_hole
J4: PD2_Amt_In; THONKICONN_hole
J5: VCA_In; THONKICONN_hole
J6: DAC1_Out; THONKICONN_hole
J7: DAC2_Out; THONKICONN_hole
J8: Eurorack_16_pin_power; Eurorack_16_pin_header
L1: L; R_0805_HandSoldering
PD1Amt1, PD1Type1, PD2Amt1, PD2Type1: B10k; Alpha_9mm_Potentiometer
R1, R10, R12, R13, R14, R15: 47k; R_0805_HandSoldering
R2: 82k; R_0805_HandSoldering
R3, R5, R7, R9: 100k; R_0805_HandSoldering
R4: 91k; R_0805_HandSoldering
R6, R8, R19, R20: 68k; R_0805_HandSoldering
R11: 56k; R_0805_HandSoldering
R16, R18: 6.8k; R_0805_HandSoldering
R17, R21, R22, R26: 680R; R_0805_HandSoldering
R23, R24: 1k; R_0805_HandSoldering
R25: 2.2k; R_0805_HandSoldering
SW1: DAC1_RingMod_Switch; SPDTSubMiniature
SW2: DAC2_Mix_Switch; SPDTSubMiniature
SW3: Octave_Switch; SPDTSubMiniature
SW4: SW_Push; SW_SPST_EVQQ2
U1: STM32F405RGTx; LQFP-64_10x10mm_P0.5mm
U2: MCP6004; SOIC-14_N
U3: TL072; SOIC-8-N
U4: LM1117-3.3; TO-252-3_TabPin2
Y1: Crystal; Crystal_SMD

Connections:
+3.3VA: CTune1.1, FTune1.1, L1.1, PD1Amt1.1, PD1Type1.1, PD2Amt1.1, PD2Type1.1, U1.13 (VDDA), U2.4 (V+)
+3V3: C1.1, C4.1, C9.1, C10.1, C25.1, J1.1, L1.2, R17.2, R21.1, R22.1, R26.1, U1.19 (VDD), U1.32 (VDD), U1.48 (VDD), U1.64 (VDD), U4.2 (VO)
+12V: D2.2 (A), J8.9, J8.10
-12V: D3.1 (K), J8.1, J8.2
AREF_-5: C24.1, D1.2 (A), R2.2, R4.2, R6.2, R8.2, R25.2
CTUNE: CTune1.2, U1.27 (PB1)
CV_IN: J2.2, J8.13, J8.14
Calibration: SW4.1, U1.57 (PB5)
DAC1_OUT: C17.2, U1.20 (PA4)
DAC1_RING_MOD: SW1.2 (B), U1.37 (PC6); also elsewhere on the board
DAC2_MIX: SW2.2 (B), U1.61 (PB8)
DAC2_OUT: C18.2, U1.21 (PA5)
FTUNE: C6.1, FTune1.2, U1.24 (PC4)
GND: C1.2, C2.2, C3.2, C4.2, C5.1, C6.2, C7.2, C8.2, C9.2, C10.2, C11.2, C12.2, C21.2, C22.2, C23.1, C24.2, C25.2, CTune1.3, D1.1 (K), FTune1.3, J1.2, J2.1, J3.1, J3.2, J4.1, J4.2, J5.1, J6.1, J7.1, J8.3, J8.4, J8.5, J8.6, J8.7, J8.8, PD1Amt1.3, PD1Type1.3, PD2Amt1.3, PD2Type1.3, R14.2, R15.2, SW1.3 (C), SW2.3 (C), U1.12 (VSSA), U1.18 (VSS), U1.63 (VSS), U2.3 (+), U2.5 (+), U2.10 (+), U2.11 (V-), U2.12 (+), U3.3 (+), U3.5 (+), U4.1 (GND); also elsewhere on the board
unnamed: C2.1, U1.5 (PH0), Y1.2
unnamed: C3.1, U1.6 (PH1), Y1.1
unnamed: C5.2, U1.31 (VCAP_1)
unnamed: C8.1, U1.47 (VCAP_2)
unnamed: C13.1, R2.1, R3.1, R10.2, U2.6 (-)
unnamed: C14.1, R4.1, R5.1, R11.2, U2.2 (-)
unnamed: C15.1, R6.1, R7.1, R12.2, U2.9 (-)
unnamed: C16.1, R8.1, R9.1, R13.2, U2.13 (-)
unnamed: C17.1, R14.1, R16.2
unnamed: C18.1, R15.1, R18.2
unnamed: C19.1, R16.1, R19.2, U3.2 (-)
unnamed: C19.2, R19.1, R23.2, U3.1
unnamed: C20.1, R18.1, R20.2, U3.6 (-)
unnamed: C20.2, R20.1, R24.2, U3.7
unnamed: J2.3, R3.2
unnamed: J3.3, R5.2
unnamed: J4.3, R7.2
unnamed: J5.2, R1.2
unnamed: J5.3, R9.2
unnamed: J6.3, R23.1
unnamed: J7.3, R24.1
unnamed: R17.1, SW3.2
unnamed 42: R21.2, SW1.1 (A); also elsewhere on the board
unnamed: R22.2, SW2.1 (A)
unnamed: R26.2, SW4.2
OCTAVE_DN: SW3.1, U1.53 (PC12)
OCTAVE_UP: SW3.3, U1.51 (PC10)
PD1_CV: C14.2, R11.1, U1.10 (PC2), U2.1
PD1_POT: C7.1, PD1Amt1.2, U1.23 (PA7)
PD1_TYPE: C12.1, PD1Type1.2, U1.15 (PA1)
PD2_CV: C15.2, R12.1, U1.17 (PA3), U2.8
PD2_POT: C11.1, PD2Amt1.2, U1.9 (PC1)
PD2_TYPE: PD2Type1.2, U1.16 (PA2)
SWCLK: J1.4, U1.49 (PA14)
SWDIO: J1.3, U1.46 (PA13)
VCA: C16.2, R13.1, U1.8 (PC0), U2.14
VCC: C21.1, C22.1, D2.1 (K), R1.1, U3.8 (V+), U4.3 (VI)
VEE: C23.2, D3.2 (A), R25.1, U3.4 (V-)
V_OCT_CV: C13.2, R10.1, U1.26 (PB0), U2.7

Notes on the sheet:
CV Input Scaling
To Do: Add Reset button Ground Boot0 Capacitors to VDDA input UART/USB IO?
Pins 19, 32, 48, 64 ground capacitors
Output Amplifiers
ADC Potentiometers
Power Sections
Switches

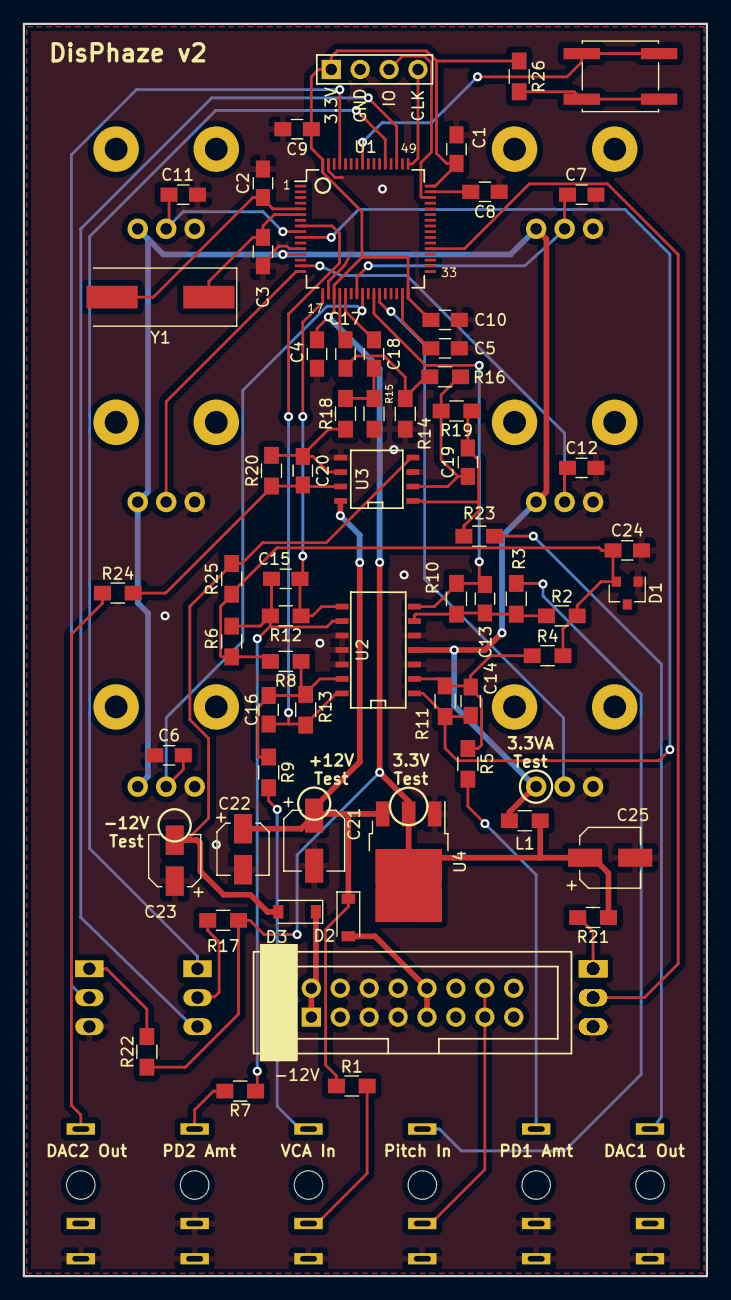
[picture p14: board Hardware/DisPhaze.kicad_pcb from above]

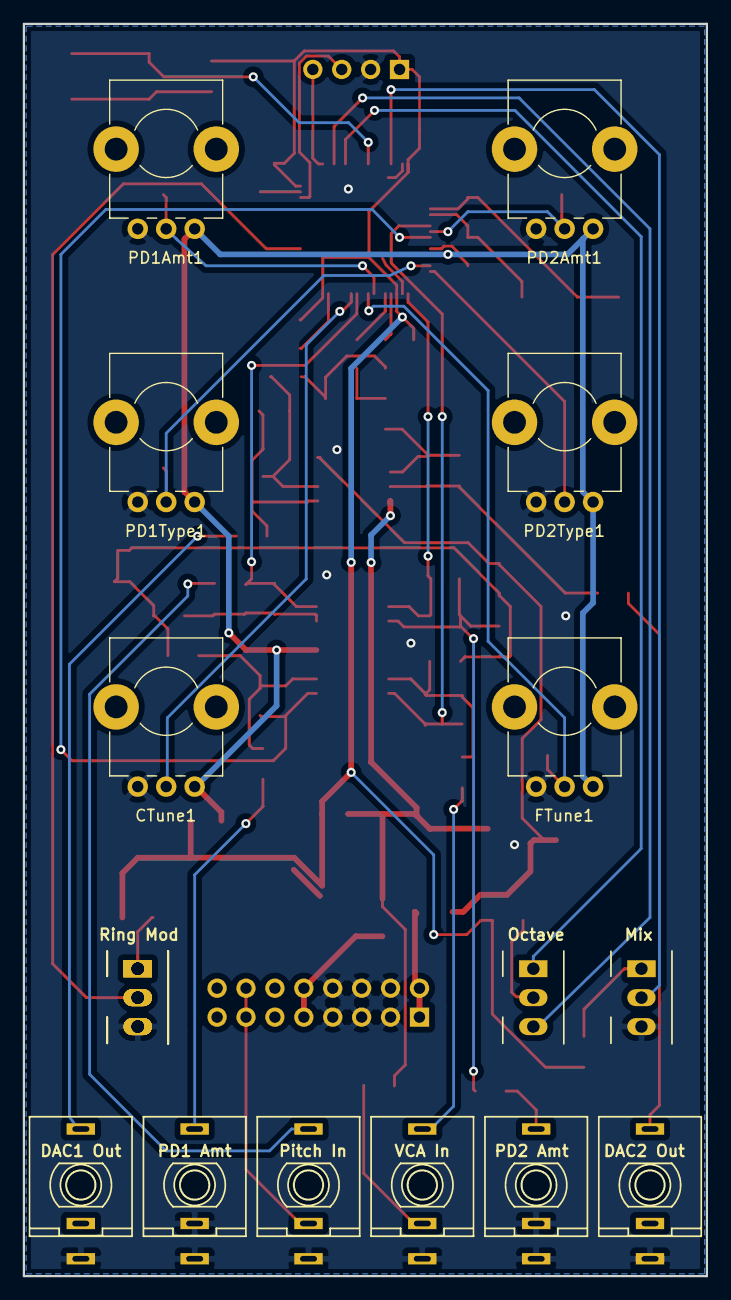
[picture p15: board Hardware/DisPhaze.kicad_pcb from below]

Board: 2 copper layers, 60.0 x 110.0 mm, 80 parts (17 on the bottom side), 53 nets.

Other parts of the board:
SW1#2, SW1#3: DAC1_RingMod_Switch; SPDTSubMiniature

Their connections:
DAC1_RING_MOD: SW1#2.2, SW1#3.2; also elsewhere on the board
GND: SW1#2.3, SW1#3.3; also elsewhere on the board
unnamed 42: SW1#2.1, SW1#3.1; also elsewhere on the board

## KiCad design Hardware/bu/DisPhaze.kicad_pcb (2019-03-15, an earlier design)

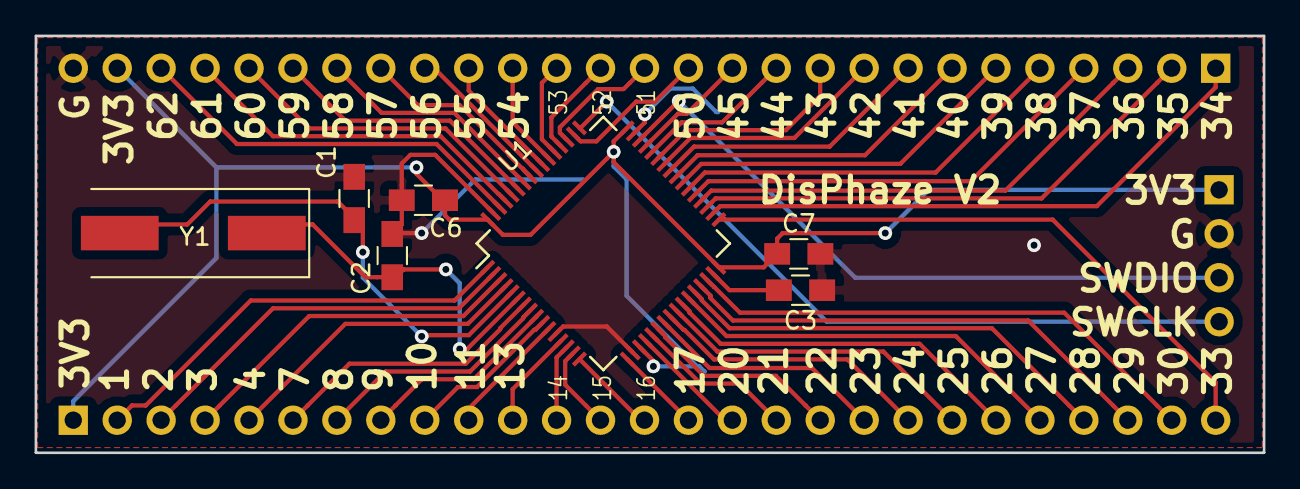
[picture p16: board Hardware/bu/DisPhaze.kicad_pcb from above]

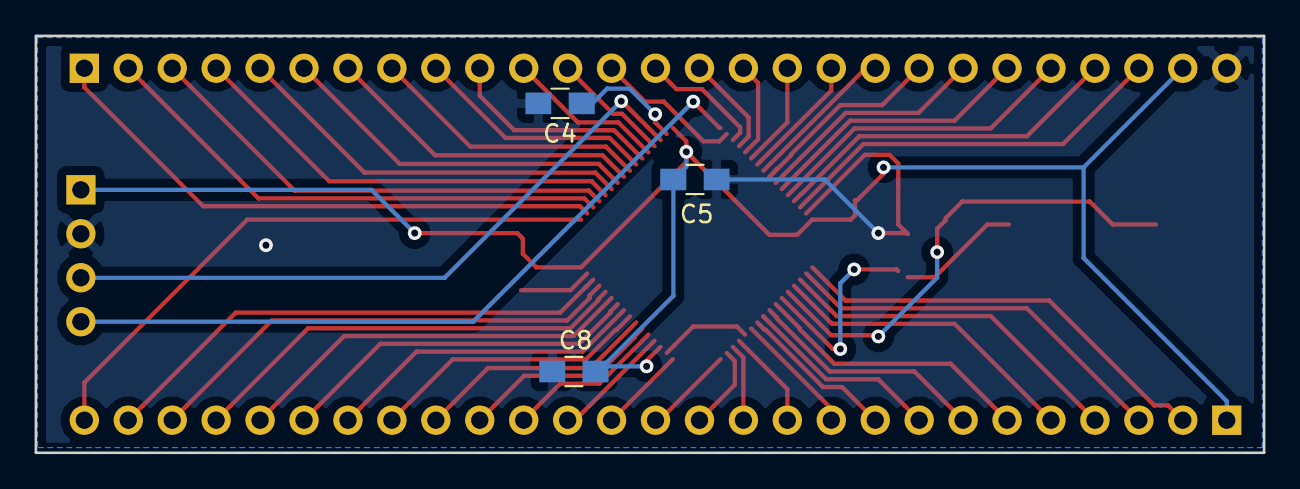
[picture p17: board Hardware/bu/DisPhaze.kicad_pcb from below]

Board: 2 copper layers, 71.0 x 24.1 mm, 13 parts (3 on the bottom side), 59 nets.

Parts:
C1, C2: 18pF; C_0805_HandSoldering
C3, C4: 2.2uF; C_0805_HandSoldering
C5, C6, C7, C8: 100nF; C_0805_HandSoldering
J1, J2: Conn_01x27; Connector_27x2.54mm
J3: Conn_01x04_Male; 4pin_header
U1: STM32F405RGTx; LQFP-64_10x10mm_P0.5mm
Y1: Crystal; Crystal_SMD_HC49-SD

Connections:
+3V3: C5.1, C6.1, C7.1, C8.1, J1.1, J2.26, J3.1, U1.19, U1.32, U1.48, U1.64
GND: C1.2, C2.2, C3.1, C4.2, C5.2, C6.2, C7.2, C8.2, J2.27, J3.2, U1.12, U1.18, U1.63
unnamed: C1.1, U1.5, Y1.2
unnamed: C2.1, U1.6, Y1.1
unnamed: C3.2, U1.31
unnamed: C4.1, U1.47
SWCLK: J3.4, U1.49
SWDIO: J3.3, U1.46
p1: J1.2, U1.1
p2: J1.3, U1.2
p3: J1.4, U1.3
p4: J1.5, U1.4
p7: J1.6, U1.7
p8: J1.7, U1.8
p9: J1.8, U1.9
p10: J1.9, U1.10
p11: J1.10, U1.11
p13: J1.11, U1.13
p14: J1.12, U1.14
p15: J1.13, U1.15
p16: J1.14, U1.16
p17: J1.15, U1.17
p20: J1.16, U1.20
p21: J1.17, U1.21
p22: J1.18, U1.22
p23: J1.19, U1.23
p24: J1.20, U1.24
p25: J1.21, U1.25
p26: J1.22, U1.26
p27: J1.23, U1.27
p28: J1.24, U1.28
p29: J1.25, U1.29
p30: J1.26, U1.30
p33: J1.27, U1.33
p34: J2.1, U1.34
p35: J2.2, U1.35
p36: J2.3, U1.36
p37: J2.4, U1.37
p38: J2.5, U1.38
p39: J2.6, U1.39
p40: J2.7, U1.40
p41: J2.8, U1.41
p42: J2.9, U1.42
p43: J2.10, U1.43
p44: J2.11, U1.44
p45: J2.12, U1.45
p50: J2.13, U1.50
p51: J2.14, U1.51
p52: J2.15, U1.52
p53: J2.16, U1.53
p54: J2.17, U1.54
p55: J2.18, U1.55
p56: J2.19, U1.56
p57: J2.20, U1.57
p58: J2.21, U1.58
p59: J2.22, U1.59
p60: J2.23, U1.60
p61: J2.24, U1.61
p62: J2.25, U1.62

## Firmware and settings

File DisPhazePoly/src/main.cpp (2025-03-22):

#include "initialisation.h"
#include "PhaseDistortion.h"
#include "configManager.h"
#include "USB.h"
#include "CDCHandler.h"
#include "Calib.h"

#if FFT_ANALYSIS
#include "fft.h"
#endif

#if (USB_DEBUG)
#include "uartHandler.h"
#endif


PhaseDistortion phaseDist;
Calib calib;

volatile uint32_t SysTickVal;
volatile uint16_t ADC_array[ADC_BUFFER_LENGTH];

extern "C" {						// Use extern C to allow linker to find ISR
#include "interrupts.h"
}

Config config{&phaseDist.configSaver, &calib.configSaver};		// Construct config handler with list of configSavers


int main(void)
{
	InitHardware();

	config.RestoreConfig();			// Restore calibration settings from flash memory and create MIDI to pitch LUT if needed
	CreateLUTs();					// Create pitch and sine wave look up tables
	InitSampleTimer();				// Sample output timer 3 - fires interrupt to trigger sample output from DAC
	phaseDist.SetSampleRate();		// Double sample rate for monophonic mode
	usb.Init(false);


	while (1) {
#if FFT_ANALYSIS
		extern bool printFFT;
		if (printFFT) {
			TIM3->CR1 &= ~TIM_CR1_CEN;
			printFFT = false;
			fft.CalcFFT();
			printf("FFT Done\r\n");
			TIM3->CR1 |= TIM_CR1_CEN;
		}
#endif

		calib.Calibrate();			// Calibration state machine
		usb.cdc.ProcessCommand();	// Check for incoming CDC commands
		config.SaveConfig();		// Save any scheduled changes
#if (USB_DEBUG)
		if (uartCmdRdy) {
			uartCommand();
		}
#endif


	}
}

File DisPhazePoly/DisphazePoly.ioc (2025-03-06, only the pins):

Mcu.UserName=STM32F405RGTx
PA11.Signal=USB_OTG_FS_DM
PA12.Signal=USB_OTG_FS_DP
PA9.Signal=USB_OTG_FS_VBUS
PH0-OSC_IN.Signal=RCC_OSC_IN
PH1-OSC_OUT.Signal=RCC_OSC_OUT

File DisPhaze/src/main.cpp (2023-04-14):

#include "initialisation.h"
#include "PhaseDistortion.h"
#include "config.h"
#include "USB.h"
#include "CDCHandler.h"

/*
 * Calibration process:
 *
 * 1. Set fine tune and both phase distortion amount knobs to the center position
 * 2. Connect a voltage source to the 1V/Oct input
 * 3. Press the calibration button once - a square wave will be output on channel 1
 * 4. The top left knob will adjust the tuning offset (will be affected by spread setting)
 * 5. The top right knob will adjust the tuning spread (test by checking different octaves)
 * 6. When the calibration is complete press the calibration button again to save
 */


extern uint32_t SystemCoreClock;
volatile uint16_t ADC_array[ADC_BUFFER_LENGTH];

bool dacRead = false;				// Tells the main loop when to queue up the next samples
volatile uint32_t overrun;			// For monitoring if samples are not being delivered to the DAC quickly enough

volatile uint32_t debugInterval;	// Debug timing counter - duration of sample interval available for calculations
volatile uint32_t debugWorkTime;	// Debug timing counter - how much time spent calculating

extern "C" {						// Use extern C to allow linker to find ISR
#include "interrupts.h"
}


int main(void)
{
	SystemInit();					// Activates floating point coprocessor and resets clock
	SystemClock_Config();			// Configure the clock and PLL
	SystemCoreClockUpdate();		// Update SystemCoreClock (system clock frequency) derived from settings of oscillators, prescalers and PLL

	config.RestoreConfig();			// Restore calibration settings from flash memory
	CreateLUTs();					// Create pitch and sine wave look up tables
	InitSwitches();					// Configure switches for Ring mod, mix and octave selection
	InitDAC();						// DAC1 Output on PA4 (Pin 20); DAC2 Output on PA5 (Pin 21)
	InitTimer();					// Sample output timer 3 - fires interrupt to trigger sample output from DAC
	InitADC();						// Configure ADC for analog controls
	InitDebugTimer();				// Timer to check available calculation time

//	usb.InitUSB();
//	usb.cdcDataHandler = std::bind(CDCHandler, std::placeholders::_1, std::placeholders::_2);

	EXTI15_10_IRQHandler();			// Call the Interrupt event handler to set up the octave up/down switch to current position
	EXTI9_5_IRQHandler();			// Call the Interrupt event handler to set up the mix switch to current position

	while (1) {
		config.Calibrate();			// Checks if calibrate button has been pressed and runs calibration routine if so

		// Ready for next sample (Calibrating sends out a square wave for tuning so disables normal output)
		if (dacRead && !config.calibrating) {
			phaseDist.CalcNextSamples();
			debugWorkTime = TIM4->CNT;
		}

		// Check for incoming CDC commands
		if (CmdPending) {
			if (!CDCCommand(ComCmd)) {
				usb.SendString("Unrecognised command. Type 'help' for supported commands\n");
			}
			CmdPending = false;
		}

	}
}

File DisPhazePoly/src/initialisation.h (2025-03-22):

#pragma once

#include "stm32f4xx.h"
#include <cstring>
#include "GpioPin.h"

static constexpr uint32_t sampleRateMono = 88000;
static constexpr uint32_t sampleRatePoly = 66000;

#define PITCH_SPREAD -583.0f
static constexpr float PITCH_OFFSET = 1129.5f;

static constexpr uint32_t sysTickInterval = 1000;
extern uint32_t SystemCoreClock;
extern volatile uint32_t SysTickVal;

static constexpr uint32_t adcMax = 4095;
#define ADC_BUFFER_LENGTH 10

#define FFT_ANALYSIS false

struct ADCValues {
	uint16_t Pitch_CV; 	// PB0 ADC12_IN8   Pin 27
	uint16_t VCA;     	// PA3 ADC123_IN3  Pin 17
	uint16_t FTune;   	// PC4 ADC12_IN14  Pin 24
	uint16_t CTune;   	// PB1 ADC12_IN9   Pin 26
	uint16_t Osc1Type;	// PC1 ADC12_IN11  Pin 9
	uint16_t Osc2Type;	// PA2 ADC123_IN2  Pin 16
	uint16_t PD1CV;   	// PC2 ADC123_IN12 Pin 10
	uint16_t PD2CV;   	// PA1 ADC123_IN1  Pin 15
	uint16_t PD1Pot;  	// PA7 ADC12_IN7   Pin 23
	uint16_t PD2Pot;  	// PC0 ADC123_IN10 Pin 8
};

extern volatile ADCValues adc;

extern GpioPin debugPin;


void InitHardware();
void InitClocks();
void InitSysTick();
void InitDAC();
void InitGPIO();
void InitSampleTimer();
void InitADC();
void InitDebugTimer();
void InitPWMTimer();
void InitMidiUART();
void DelayMS(uint32_t ms);
void JumpToBootloader();

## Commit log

2019-03-07 Added ADC control over OSC2 PD
2019-03-15 Added Kicad files and support for mix switch
    [DisPhaze.kicad_pcb, DisPhaze.sch]
2019-03-15 Schematic tidied up and command prefetch enabled
    Prefetch seems to have caused issues for some revisions but tested fine with revision Y and performance improvements seen
    [DisPhaze.sch]
2019-03-15 Tweaks to output amplifier and VCA normal
    [DisPhaze.sch]
2019-03-18 Start PCB layout
    [DisPhaze.kicad_pcb, DisPhaze.sch]
2019-03-18 First schematic draft
    [DisPhaze.kicad_pcb, _saved_DisPhaze.sch]
2019-03-19 Tweaks to pcb layout v1
    [DisPhaze.kicad_pcb, DisPhaze.sch, _saved_DisPhaze.sch]
2019-03-19 rev2 branch test
    [DisPhaze.kicad_pcb]
2019-03-19 rev2 pcb layout
    [DisPhaze.kicad_pcb]
2019-03-19 rev2 layout completed
    [DisPhaze.kicad_pcb, _saved_DisPhaze.sch]
2019-03-19 Updated GitIgnore
    [DisPhaze.sch, _saved_DisPhaze.sch]
2019-03-20 Updated schematic silk screen
    [DisPhaze.kicad_pcb]
2019-03-20 Panel outline first draft
    [DisPhaze.kicad_pcb, DisPhaze.sch, DisPhaze_Panel.kicad_pcb]
2019-03-23 Panel First Draft
    [DisPhaze_Panel.kicad_pcb]
2019-03-24 Added basic calibration and further tweaks to panel
    [DisPhaze.kicad_pcb, DisPhaze.sch, DisPhaze_Panel.kicad_pcb]
2019-03-27 Calibration settings can be saved to Flash memory and finalised PCB and panel for manufacture
    [DisPhaze.kicad_pcb, DisPhaze_Panel.kicad_pcb]
2019-03-28 Added 3d models to PCB layout
    [DisPhaze.kicad_pcb, _saved_DisPhaze.sch]
2019-04-05 Fixes to PCB silkscreen; Fixes to ADC function
    [DisPhaze.kicad_pcb, DisPhaze.sch, _saved_DisPhaze.sch]
2019-04-07 Damping to ADC controls; various contol and performance tweaks to support finished PCB
2019-11-09 Relocated and reorganised repository
    [Disphaze_Larger_MCU_Pads.kicad_pcb]
2020-10-06 Added revised panel designs; Added helper functions
    [DisPhaze.sch, DisPhaze_Panel_mk2.5.kicad_pcb, DisPhaze_Panel_mk3.kicad_pcb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]
2020-10-08 Revised version of 2.5 layout
    [DisPhaze_Panel_mk2.5.kicad_pcb]
2020-10-15 New Panel sent for manufacture
    [DisPhaze_Panel.kicad_pcb, DisPhaze_Panel_mk2.5.kicad_pcb, DisPhaze_Panel_mk3.kicad_pcb]
2021-05-18 Tweaks to ADC handling
2021-05-20 Added calibration functionality; updated library and startup code
    [DisPhaze.sch]
2021-05-20 Enabled data and instruction cache; Increased optimizer to O1 for doubling of performance
    [DisPhaze.kicad_pcb]
2022-02-21 Calibration changes applied immediately; extended readme. Kicad files updated to v6.0
    [DisPhaze.kicad_pcb, DisPhaze.kicad_sch]
2022-03-11 Phase distortion generation now handled with python scripts
    [LUT generator.xlsx]
2022-03-11 Removed old C++ sample extract project to bu
2022-03-18 Started layout of v3 board
    [DisPhaze_Components.kicad_pcb, DisPhaze_Components.kicad_sch, DisPhaze_Panel.kicad_pcb]
2022-03-18 Updated panel to incorporate v3 redesign
    [DisPhaze_Components.kicad_pcb, DisPhaze_Components.kicad_sch, DisPhaze_Panel.kicad_pcb]
2022-03-19 Added photocoupler to MIDI Input
    [DisPhaze_Components.kicad_pcb, DisPhaze_Components.kicad_sch, DisPhaze_Panel.kicad_pcb]
2022-03-20 Replaced optocoupler with transistor pair. Changed bi-colour LED to 3 lead device
    [DisPhaze_Components.kicad_pcb, DisPhaze_Components.kicad_sch]
2022-03-22 Preparation of Gerbers for v3 hardware ordering
    [DisPhaze_Components.kicad_pcb, DisPhaze_Components.kicad_sch, DisPhaze_Panel.kicad_pcb]
2022-03-22 Implemented basic USB device (CDC, MIDI)
2022-05-01 Started implementing v3 Polyphonic changes
    [DisPhaze_Components.kicad_pcb, DisPhaze_Components.kicad_sch]
2022-05-01 PWM Control of Green/Red LED working
2022-05-02 PWM and control clean up
2022-05-06 Optimising local variables; reduced sample rate from 72k to 60k
2022-05-07 Serial MIDI basically working; started adding errata to schematic
    [DisPhaze_Components.kicad_sch]
2022-05-08 Basic support for pitch bends and fine tuning in polyphonic mode
2022-05-09 Improved MIDI pitch bend handling; changed sample rate to 48kHz
2022-05-12 Updates to compression algorithm; bug fixes
    [PhaseDistortion.cpp, PhaseDistortion.h, main.cpp]
2022-05-12 LED reflects level in poly/mono mode; started implementing action button
    NB hardware problem found where pressing action button seems to create a glitch - should be rewired to connect to ground via internal pull-up
    [PhaseDistortion.cpp, PhaseDistortion.h, initialisation.cpp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]
2022-05-13 Started implementing envelope detection
    [DisPhaze_Components.kicad_sch]
2022-05-18 Bug fixes to envelope detection and generation routines
    [PhaseDistortion.cpp, PhaseDistortion.h]
2022-05-20 Long press on action button switches polyphonic/monophonic
    Started work revising polyphonic compressor
2022-05-31 Added some output filtering; Midi LUT saved to Flash directly
    Changed sample rate to 44kHz
2023-04-14 Cleaned up projects to fix errors in latest CubeIDE version
    [DisphazePoly.ioc, PhaseDistortion.cpp, main.cpp]
2023-04-14 Prepare to move pitch input from ADC1 to ADC2
2023-04-14 Added pitch adjustment mechanism to compensate for tuning errors around ADC centre point
    [PhaseDistortion.cpp, PhaseDistortion.h, USB.cpp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]
2025-03-06 Clean up of Disphaze v2 firmware
    [DisPhaze_Components.kicad_pcb, DisPhaze_Components.kicad_sch]
2025-03-06 Monophonic Mode doubles sample rate
2025-03-06 Fixed LUT size issues
    [PhaseDistortion.cpp]
2025-03-10 Started adding LED handler; fixes to USB under Linux
    [PhaseDistortion.cpp, PhaseDistortion.h, USB.cpp]
2025-03-12 Gpio class button handles both pull up/down
    Also added pull downs to switch pins
    [DisPhaze_Components.kicad_sch]
2025-03-14 New config saving and calibration mechanisms
2025-03-18 Use 32 bit integers to speed up sample position logic
2025-03-21 Fixes to LED handling
    [DisPhaze_Components.kicad_sch]
2025-03-21 Polyphonic envelopes stored in seconds (rather than samples)
2025-03-22 Updates to schematic; fixes for stuck MIDI notes
    [PhaseDistortion.cpp, initialisation.cpp, initialisation.h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]
2025-03-22 More handling for MIDI issues
    [DisPhaze_Components.kicad_pcb, DisPhaze_Components.kicad_sch]
2025-03-23 Fixed pd1 not responding in mono mode
    Split original v3 schematics
    [DisPhaze_Components.kicad_pcb, DisPhaze_Components.kicad_sch, DisPhaze_Panel.kicad_pcb]
2025-03-24 Fixes to mix mode
    [PhaseDistortion.cpp, PhaseDistortion.h]
